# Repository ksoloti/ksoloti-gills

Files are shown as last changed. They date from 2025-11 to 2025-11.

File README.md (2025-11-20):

# ksoloti-gills
# CAD project and Gerbers for Ksoloti Gills v0.6

# Kicad 9.0!

## This is just the Gills unit (and CV expander) and will not work without a Ksoloti Core plugged in.

# Gills PCB
`Gerbers`, `BOM` and `CPL` files for the PCB are in the subfolder [/jlcpcb/production_files](https://github.com/ksoloti/ksoloti-gills/tree/main/jlcpcb/production_files)

Schematics are [here](https://github.com/ksoloti/ksoloti-gills/blob/main/ksoloti-gills_v06.pdf)

Human-readable BOM with notes and links is [here](https://github.com/ksoloti/ksoloti-gills/blob/main/ksoloti-gills_v06_bom.xlsx)

Screenshot from 2025-11-19 20-59-49

Screenshot from 2025-11-19 20-59-14

Screenshot from 2025-11-19 20-59-08

# Gills Enclosure Panels

`Gerbers` for the enclosure panels are in the subfolder [/ksoloti-gills_panel/jlcpcb/production_files](https://github.com/ksoloti/ksoloti-gills/tree/main/ksoloti-gills_panel/jlcpcb/production_files)
Although the Kicad project includes all panels, there is one gerber zip per panel: top, bottom, left, right, front, rear. If you have made edits and want to update the Gerbers, you will need to create separate Gerbers by pasting each relevant single panel in a temporary PCBNew window and `File->Plot...` it from there. Or so.
Note that there are two `ksoloti-gills-panel-top-*.zip`, one for black color, one for white. The silkscreens differ.

Screenshot from 2025-11-20 00-12-38

# Gills CV Expander PCB
`Gerbers`, `BOM` and `CPL` files for the CV Expander PCB are in the subfolder [/ksoloti-gills-cv-expander/jlcpcb/production_files](https://github.com/ksoloti/ksoloti-gills/tree/main/jlcpcb/production_files)

CV Expander Schematics are [here](https://github.com/ksoloti/ksoloti-gills/blob/main/ksoloti-gills-cv-expander/ksoloti-gills-cv-expander_v03.pdf)

BOM parts required for CV Expander are included in the main BOM (xlsx) above.

Screenshot from 2025-11-20 00-50-47

Screenshot from 2025-11-20 00-50-07

Screenshot from 2025-11-20 00-50-03

## About Licensing and Sharing 

This hardware design is shared under the "Creative Commons Attribution 4.0 International Public License" (CC BY 4.0).
This means you can use this design for almost anything, including commercial projects. You are totally free to reproduce, share, and modify it.

Because this is a physical hardware project, we ask for two small favours to keep the attribution clear:
- Keep the attribution text "CC BY 4.0 Ksoloti" on the silkscreen layer.
- If you make any significant edits and share your modified version, please note what modifications you've made. Do add something like "edit by <yourname>" if you like!

The full, official legal text is available in the `LICENSE` file in this repository. Happy hacking!

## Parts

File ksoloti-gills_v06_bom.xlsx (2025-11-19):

Source: | ksoloti_gills_v06
Date: | 14 Nov 2025 15:10:09 CST
Ref | Qnty | Value | Cmp name | Footprint | Description | Example
C53 | 1 | 1000uF – 2200uF, 10V+ | C_Polarized_Small | Capacitor_THT:CP_Radial_D10.0mm_P5.00mm | Polarized capacitor, small symbol
ENC1 | 1 | STEC11 | RotaryEncoder_Switch_GND | Library:ALPS_STEC11 | Rotary encoder, dual channel, incremental quadrate outputs, with switch, 20mm shaft | (T18 shaft:) https://www.amazon.com/Taiss-Detents-Points-Encoder-Diameter/dp/B07F24TRYG (D-shaft:) https://www.mouser.com/ProductDetail/Alps-Alpine/EC11E1534408?qs=PoKhxlfUXjJk5yy1jIb28A%3D%3D
H1, H3 | 2 | Conn_02x12_Female | Conn_02x12_Female | Library:PinSocket_2x12_P2.54mm_Vertical_smcrt_sqr | Generic connector, double row, 02x12, script generated (kicad-library-utils/schlib/autogen/connector/)
H2 | 2 | Conn_02x02_Female | Conn_02x02_Female | Library:PinSocket_2x02_P2.54mm_Vertical_smcrt_sqr | Generic connector, double row, 02x02, script generated (kicad-library-utils/schlib/autogen/connector/)
J1 | 1 | 9-20VDC | Barrel_Jack_Switch | Library:dc_socket_2.1mm_5.5mm | DC Barrel Jack with an internal switch | https://www.mouser.com/ProductDetail/Gravitech/CON-SOCJ-2155?qs=fkzBJ5HM%252BdCcpvFQyQZHtA%3D%3D
J3, J4, J5, J6, J7 | 5 | IN_L, IN_R, OUT_L, OUT_R, HP_OUT | AudioJack3_Switch | Library:Jack_6.35mm_Neutrik_NRJ6HF_Horizontal_no_screwhole | Audio Jack, 3 Poles (Stereo / TRS), Switched Poles (Normalling) | https://www.mouser.com/ProductDetail/Neutrik/NRJ6HF-1?qs=lytv%2F56AjyI%252Bc%252Bp%2FfWZpBw%3D%3D
J3n, J4n, J5n, J6n | 4 | JUST_NUTS | AudioJack3_Switch_nut | Library:Jack_6.35mm_Neutrik_NRJ6HF_Horizontal_no_screwhole_nut | Plastic nut for Audio Jack, 3 Poles (Stereo / TRS), Switched Poles (Normalling) | https://www.mouser.com/ProductDetail/Neutrik/NRJ-NUT-B?qs=S12Y1JoqO2A%2FB2tjq8cO2w%3D%3D
J8, J9 | 3 | EXP_IO1, EXP_IO2, GATE_OUT | AudioJack4 | Library:PJ-320A_THT | Audio Jack, 4 Poles (TRRS) | https://42keebs.eu/shop/parts/components/pj-320-trrs-socket/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 https://www.taydaelectronics.com/pj-320a-3-5-mm-audio-socket-through-hole-pcb-silver-plated.html
J10, J11 | 2 | MIDI_OUT, MIDI_IO | DIN-5_180degree | Library:MIDI_DIN-5_DS-5-01c | 5-pin DIN connector (5-pin DIN-5 stereo) | https://www.mouser.com/ProductDetail/Kycon/KCDX-5S-N?qs=uMQTibCNu0QKDGeRAj6hLg%3D%3D
J12 | 1 | LINE_IN_OUT | Conn_01x06_Female | Connector_PinSocket_2.54mm:PinSocket_1x06_P2.54mm_Vertical | Generic connector, single row, 01x06, script generated (kicad-library-utils/schlib/autogen/connector/)
J13 | 1 | HP_OUT | Conn_01x03_Female | Connector_PinSocket_2.54mm:PinSocket_1x03_P2.54mm_Vertical | Generic connector, single row, 01x03, script generated (kicad-library-utils/schlib/autogen/connector/)
LED1 | 1 | GREEN | LED | Library:LED_D3.0mm_marked | Light emitting diode | https://www.mouser.com/ProductDetail/Kingbright/WP710A10SGD?qs=jBF9H7RTBaS5vBvRdVQZww%3D%3D
LED2 | 1 | RED | LED | Library:LED_D3.0mm_marked | Light emitting diode | https://www.mouser.com/ProductDetail/Kingbright/WP710A10ID?qs=wRBQ8ZgBZ98VyHeNIlWGkQ%3D%3D
LED3, LED4 | 2 | LED_Dual_AKA | LED_Dual_AKA | Library:LED_D3.0mm-3_marked | Dual LED, common cathode on pin 2 | https://www.mouser.com/ProductDetail/Kingbright/WP115VEGW?qs=58z0TXQGVSQe%2FVnyoskf7A%3D%3D
LED standoffs | 4 | LED standoffs | LED standoffs | - | Standoffs for 3mm LED, plastic, 4mm height. 2 pcs for 2-pin LED, 2 pcs for 3-pin LED.
OLED1 | 1 | 128x64_OLED | display_i2c_oled | Library:128x64OLED_1_3in, SH1106, white | 1.3inch OLED, 4-pin header, I2c, SH1106, white, pinout GND-VCC-SCL-SDA. Exact dimensions are a bit tricky to get as there are various manufacturers. The one used in Gills is by Shenzhen Enrich Electronics, model ENH-OB0130011A
RV1, RV2, RV3, RV4, RV5, RV6, RV7, RV8, RV9, RV10 | 10 | B10k | R_POT_GND | Library:ALPS_POT_VERTICAL_PS | Potentiometer
RV11, RV12 | 2 | 2*B100k | R_POT_Dual_Separate_GND | Library:ALPS_POT_VERTICAL_PS_DUAL | Dual potentiometer, separate units
SW1, SW2, SW3, SW4 | 4 | TL1105 | TL1105 | Library:TL1105T | Double Pole Single Throw (DPST) Switch Momentary tact switch, 6*6mm. With 6.5mm diameter circular cap. | (standard click:) https://www.mouser.com/ProductDetail/CUI-Devices/TS02-66-120-BK-160-LCR-D?qs=A6eO%252BMLsxmT55wwvoE7v5Q%3D%3D (very light click:) https://www.mouser.com/ProductDetail/CUI-Devices/TS02-66-120-BK-100-LCR-D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
H1, H2, H3 (Core) | 3 | Conn_02x12_Male | Conn_02x12_Male | Library:PinHeader_2x12_P2.54mm_Vertical_smcrt_sqr | Generic connector, double row, 02x12, script generated (kicad-library-utils/schlib/autogen/connector/)
J1 (Core) | 1 | Conn_01x06_Male | Conn_01x06_Male | Library:PinHeader_1x06_P2.54mm_Vertical_smcrt_sqr | Generic connector, single row, 01x06, script generated (kicad-library-utils/schlib/autogen/connector/)
J2 (Core) | 1 | Conn_01x03_Male | Conn_01x03_Male | Library:PinHeader_1x03_P2.54mm_Vertical_smcrt_sqr | Generic connector, single row, 01x03, script generated (kicad-library-utils/schlib/autogen/connector/)
PDM mic header (Core) | 1 | Conn_01x02_Male | Conn_01x02_Male | Library:PinHeader_1x02_P2.54mm_Vertical_smcrt_sqr | Optional. Connects the digital Mic clock and data lines to the Core.
J1 (CV Expander) | 1 | Conn_02x03_Male | Conn_02x03_Male | Library:PinHeader_2x03_P2.54mm_Vertical_smcrt_sqr | Generic connector, double row, 02x03, script generated (kicad-library-utils/schlib/autogen/connector/)
TR1, TR2, TR3, TR4 (CV Expander) | 4 | 50k | Trimmer Bourns 3266P | Potentiometer_THT:Potentiometer_Bourns_3266P_Horizontal | Trimmer Potentiometer, Bourns 3266P Horizontal, 50k | https://www.digikey.tw/en/products/detail/bourns-inc/3266P-1-503/3722092
HEAT1 | 1 | Isolation tape, or Heatshrink, 3-4mm diameter, ca. 3cm length (optional) |  |  | Optional. For shielding LED1 and LED2 against light bleed from each other.
J14 (HP_POT) | 1 | 2*B1k to 2*B5k | R_POT_Dual_Separate_GND | Library:ALPS_POT_VERTICAL_PS_DUAL_HORIZONTAL | Optional headphone control. Involves drilling a hole. B1k recommended but can be as low as 500R or as high as 5k, with varying response. See “Optional Headphone Volume Control” here: ksoloti.github.io/6-1-gills_build_guide.html | Example (the right value may not be in stock!): smallbear-electronics.mybigcommerce.com/dual-gang-9mm-pc-mount/
U1 | 1 | M24512 | EEPROM | Package_SO:SOIC-8_3.9x4.9mm_P1.27mm | Optional 512kbit (64kByte) I2C EEPROM. STMicroelectronics M24512-RMN6 or M24512-WMN6 recommended. | https://www.mouser.tw/ProductDetail/STMicroelectronics/M24512-RMN6TP?qs=Mr75jesUWTdqo%252BCvXQQhAg%3D%3D https://www.mouser.tw/ProductDetail/STMicroelectronics/M24512-WMN6TP?qs=Djavi1aLnwqcyh9vtkZgnQ%3D%3D
Core PCB | 1 | Core PCB | Core PCB |  | Core PCB, 59mm * 89mm
Gills PCB | 1 | Gills PCB | Gills PCB |  | Gills PCB, 150mm * 92mm
Gills CV Expander PCB | 1 | Gills CV Expander PCB | Gills CV Expander PCB |  | Gills CV Expander PCB, 74mm * 70.5mm
Gills Enclosure | 1 | Gills Enclosure | Gills Enclosure |  | Gills enclosure consisting of 6 PCB panels: top, bottom, left, right, front, rear.
Hardware | 5 | M3 standoff, brass, male/female, 10mm | M3 standoff, brass, male/female, 10mm |  | Fix Gills enclosure top panel to Gills PCB
Hardware | 4 | M3 standoff, brass, female/female, 20mm | M3 standoff, brass, female/female, 20mm |  | Fix Gills enclosure bottom panel to Gills PCB
Hardware | 2 | M3 standoff, brass, male/female, 12mm | M3 standoff, brass, male/female, 12mm |  | Fix Ksoloti Core to Gills PCB
Hardware | 3 | M3 standoff, nylon, male/female, 6mm | M3 standoff, nylon, male/female, 6mm |  | Fix OLED display to Gills PCB
Hardware | 2 | M3 nut | M3 nut |  | Fix Ksoloti Core to Gills PCB
Hardware | 11 | M3 hex screw, black alloy, button head, 6mm | M3 hex screw, black alloy, button head, 6mm |  | 5 screws on top panel, 4 screws on bottom panel, 2 screws on OLED module
Hardware | 12 | Potentiometer nut, M6? M7? | Potentiometer nut, M6? M7? | Usually included with the pots | Encoder does not get one.

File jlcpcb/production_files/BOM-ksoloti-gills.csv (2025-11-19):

Comment | Designator | Footprint | LCSC | Quantity
100 ohm @ 100 Mhz | FB6,FB7 | R_0805_2012Metric | C1015 | 2
100 ohm @ 100 Mhz | FB1,FB2,FB3,FB4,FB5 | R_1206_3216Metric | C98293 | 5
100n | C11,C12,C13,C16,C29,C30,C33,C35,C39,C7,C8,C9 | C_0603_1608Metric | C14663 | 12
10k | R13,R31,R39,R40,R41,R44,R45 | R_0603_1608Metric | C25804 | 7
10n | C34 | C_0603_1608Metric | C57112 | 1
10u_25V | C10,C41 | C_0603_1608Metric | C96446 | 2
15uh | L1 | L_7.3x6.7_H3.5 | C2847544 | 1
1N4148WS | D4 | D_SOD-323 | C2128 | 1
1N5819WS | D5,D6,D7,D8 | D_SOD-323 | C191023 | 4
1k | R1,R12,R15,R16,R17,R19,R2,R3,R37,R4,R42,R43,R5,R6,R7,R8,R9 | R_0603_1608Metric | C21190 | 17
2.2u | C1,C2,C27,C28,C3,C31,C32,C4,C5,C6 | C_0603_1608Metric | C23630 | 10
2.7k | R35,R36 | R_0603_1608Metric | C13167 | 2
220 | R20,R21,R22,R23,R24,R33,R46,R48,R52,R53,R54,R55,R58,R59,R68 | R_0603_1608Metric | C22962 | 15
3V3 | D2 | D_MiniMELF | C7497475 | 1
3k | R49 | R_0603_1608Metric | C4211 | 1
47k | R25,R34,R47,R56,R57 | R_0603_1608Metric | C25819 | 5
47u | C36,C37,C38,C54 | C_1206_3216Metric | C96123 | 4
6N137 | U5 | SMDIP-8_W9.53mm | C110020 | 1
74LVC2G17 | U2,U9 | SOT-23-6 | C10429 | 2
M24512 | U1 | SOIC-8_3.9x4.9mm_P1.27mm | C79991 | 1
RGREEN | R10,R11,R18 | R_0805_2012Metric | C17630 | 3
RRED | R14,R32,R38 | R_0805_2012Metric | C17557 | 3
SS34 | D1,D3 | D_SMA | C8678 | 2
TPS5430DDA | U4 | TI_SO-PowerPAD-8_ThermalVias | C9864 | 1
MountingHole | MH7 | MountingHole_3.2mm_M3_Pad_Via_tight |  | 1
MountingHole | MH8 | MountingHole_3.2mm_M3_Pad_Via_tight |  | 1
MountingHole | MH5 | MountingHole_3.2mm_M3_Pad_Via_tight |  | 1
MountingHole | MH6 | MountingHole_3.2mm_M3_Pad_Via_tight |  | 1
B10k | RV1 | ALPS_POT_VERTICAL_PS |  | 1
LED_Dual_AKA | LED3 | LED_D3.0mm-3_marked |  | 1
B10k | RV4 | ALPS_POT_VERTICAL_PS |  | 1
LINE_IN_OUT | J12 | PinSocket_1x06_P2.54mm_Vertical |  | 1
LED_Dual_AKA | LED4 | LED_D3.0mm-3_marked |  | 1
B10k | RV2 | ALPS_POT_VERTICAL_PS |  | 1
2*B100k | RV11 | ALPS_POT_VERTICAL_PS_DUAL |  | 1
HP_POT | J14 | PinHeader_2x03_P2.54mm_Vertical |  | 1
TL1105 | SW1 | TL1105T |  | 1
TL1105 | SW4 | TL1105T |  | 1
TL1105 | SW2 | TL1105T |  | 1
B10k | RV3 | ALPS_POT_VERTICAL_PS |  | 1
MIDI_IO | J11 | MIDI_DIN-5_DS-5-01c |  | 1
B10k | RV10 | ALPS_POT_VERTICAL_PS |  | 1
B10k | RV9 | ALPS_POT_VERTICAL_PS |  | 1
B10k | RV6 | ALPS_POT_VERTICAL_PS |  | 1
MountingHole | MH4 | MountingHole_3.2mm_M3_Pad_Via_tight |  | 1
2*B100k | RV12 | ALPS_POT_VERTICAL_PS_DUAL |  | 1
RED | LED2 | LED_D3.0mm_marked |  | 1
STEC11 | ENC1 | ALPS_STEC12E08 |  | 1
B10k | RV7 | ALPS_POT_VERTICAL_PS |  | 1
TL1105 | SW3 | TL1105T |  | 1
B10k | RV5 | ALPS_POT_VERTICAL_PS |  | 1
MountingHole | MH1 | MountingHole_3.2mm_M3_Pad_Via_tight |  | 1
B10k | RV8 | ALPS_POT_VERTICAL_PS |  | 1
HP_OUT | J13 | PinSocket_1x03_P2.54mm_Vertical |  | 1
128x64_OLED | OLED1 | 128x64OLED_1_3in |  | 1
GREEN | LED1 | LED_D3.0mm_marked |  | 1
IN_L | J3 | Jack_6.35mm_Neutrik_NRJ6HF_Horizontal_no_screwhole |  | 1
Conn_01x01_Female | H2_P21 | PinSocket_1x01_P2.54mm_Vertical_smcrt_round |  | 1
Conn_01x01_Female | H1_P12 | PinSocket_1x01_P2.54mm_Vertical_smcrt_round |  | 1
Conn_01x01_Female | H3_P2 | PinSocket_1x01_P2.54mm_Vertical_smcrt_round |  | 1
Conn_01x01_Female | H1_P13 | PinSocket_1x01_P2.54mm_Vertical_smcrt_round |  | 1
Conn_01x01_Female | H3_P4 | PinSocket_1x01_P2.54mm_Vertical_smcrt_round |  | 1
Conn_01x01_Female | H1_P22 | PinSocket_1x01_P2.54mm_Vertical_smcrt_round |  | 1
Conn_01x01_Female | H3_P17 | PinSocket_1x01_P2.54mm_Vertical_smcrt_round |  | 1
Conn_01x01_Female | H3_P19 | PinSocket_1x01_P2.54mm_Vertical_smcrt_round |  | 1
HP_OUT | J7 | Jack_6.35mm_Neutrik_NRJ6HF_Horizontal_no_screwhole |  | 1
OUT_R | J6 | Jack_6.35mm_Neutrik_NRJ6HF_Horizontal_no_screwhole |  | 1
Conn_01x01_Female | H3_P22 | PinSocket_1x01_P2.54mm_Vertical_smcrt_round |  | 1
Conn_01x01_Female | H3_P15 | PinSocket_1x01_P2.54mm_Vertical_smcrt_round |  | 1
EXP_IO | J8 | PJ-320A_THT |  | 1
MIDI_OUT | J10 | MIDI_DIN-5_DS-5-01c |  | 1
Conn_01x01_Female | H3_P23 | PinSocket_1x01_P2.54mm_Vertical_smcrt_round |  | 1
Conn_01x01_Female | H3_P16 | PinSocket_1x01_P2.54mm_Vertical_smcrt_round |  | 1
Conn_01x01_Female | H1_P17 | PinSocket_1x01_P2.54mm_Vertical_smcrt_round |  | 1
Conn_01x01_Female | H3_P8 | PinSocket_1x01_P2.54mm_Vertical_smcrt_round |  | 1
Conn_01x01_Female | H3_P14 | PinSocket_1x01_P2.54mm_Vertical_smcrt_round |  | 1
Conn_01x01_Female | H1_P23 | PinSocket_1x01_P2.54mm_Vertical_smcrt_round |  | 1
Conn_01x01_Female | H2_P23 | PinSocket_1x01_P2.54mm_Vertical_smcrt_round |  | 1
Conn_01x01_Female | H3_P11 | PinSocket_1x01_P2.54mm_Vertical_smcrt_round |  | 1
Conn_01x01_Female | H2_P22 | PinSocket_1x01_P2.54mm_Vertical_smcrt_round |  | 1
Conn_01x01_Female | H1_P18 | PinSocket_1x01_P2.54mm_Vertical_smcrt_round |  | 1
Conn_01x01_Female | H3_P1 | PinSocket_1x01_P2.54mm_Vertical_smcrt_sqr |  | 1
Conn_01x01_Female | H3_P24 | PinSocket_1x01_P2.54mm_Vertical_smcrt_round |  | 1
Conn_01x01_Female | H1_P7 | PinSocket_1x01_P2.54mm_Vertical_smcrt_round |  | 1
Conn_01x01_Female | H3_P5 | PinSocket_1x01_P2.54mm_Vertical_smcrt_round |  | 1
Conn_01x01_Female | H3_P20 | PinSocket_1x01_P2.54mm_Vertical_smcrt_round |  | 1
Conn_01x01_Female | H3_P21 | PinSocket_1x01_P2.54mm_Vertical_smcrt_round |  | 1
OUT_L | J5 | Jack_6.35mm_Neutrik_NRJ6HF_Horizontal_no_screwhole |  | 1
Conn_01x01_Female | H1_P21 | PinSocket_1x01_P2.54mm_Vertical_smcrt_round |  | 1
9-20VDC | J1 | dc_socket |  | 1
Conn_01x01_Female | H1_P2 | PinSocket_1x01_P2.54mm_Vertical_smcrt_round |  | 1
Conn_01x01_Female | H1_P19 | PinSocket_1x01_P2.54mm_Vertical_smcrt_round |  | 1
Conn_01x01_Female | H1_P9 | PinSocket_1x01_P2.54mm_Vertical_smcrt_round |  | 1
Conn_01x01_Female | H1_P11 | PinSocket_1x01_P2.54mm_Vertical_smcrt_round |  | 1
Conn_01x01_Female | H3_P3 | PinSocket_1x01_P2.54mm_Vertical_smcrt_round |  | 1
Conn_01x01_Female | H1_P10 | PinSocket_1x01_P2.54mm_Vertical_smcrt_round |  | 1
PWR_SWITCH | J2 | PinHeader_1x02_P2.54mm_Vertical |  | 1
Conn_01x01_Female | H1_P3 | PinSocket_1x01_P2.54mm_Vertical_smcrt_round |  | 1
Conn_01x01_Female | H2_P24 | PinSocket_1x01_P2.54mm_Vertical_smcrt_round |  | 1
Conn_01x01_Female | H3_P10 | PinSocket_1x01_P2.54mm_Vertical_smcrt_round |  | 1
Conn_01x01_Female | H1_P8 | PinSocket_1x01_P2.54mm_Vertical_smcrt_round |  | 1
Conn_01x01_Female | H3_P18 | PinSocket_1x01_P2.54mm_Vertical_smcrt_round |  | 1
Conn_01x01_Female | H3_P7 | PinSocket_1x01_P2.54mm_Vertical_smcrt_round |  | 1
Conn_01x01_Female | H3_P12 | PinSocket_1x01_P2.54mm_Vertical_smcrt_round |  | 1
Conn_01x01_Female | H1_P15 | PinSocket_1x01_P2.54mm_Vertical_smcrt_round |  | 1
EXP_IO | J9 | PJ-320A_THT |  | 1
Conn_01x01_Female | H3_P9 | PinSocket_1x01_P2.54mm_Vertical_smcrt_round |  | 1
Conn_01x01_Female | H1_P6 | PinSocket_1x01_P2.54mm_Vertical_smcrt_round |  | 1
Conn_01x01_Female | H1_P20 | PinSocket_1x01_P2.54mm_Vertical_smcrt_round |  | 1
Conn_01x01_Female | H1_P4 | PinSocket_1x01_P2.54mm_Vertical_smcrt_round |  | 1
Conn_01x01_Female | H1_P24 | PinSocket_1x01_P2.54mm_Vertical_smcrt_round |  | 1
IN_R | J4 | Jack_6.35mm_Neutrik_NRJ6HF_Horizontal_no_screwhole |  | 1
Conn_01x01_Female | H3_P6 | PinSocket_1x01_P2.54mm_Vertical_smcrt_round |  | 1
Conn_01x01_Female | H3_P13 | PinSocket_1x01_P2.54mm_Vertical_smcrt_round |  | 1
Conn_01x01_Female | H1_P1 | PinSocket_1x01_P2.54mm_Vertical_smcrt_sqr |  | 1
Conn_01x01_Female | H1_P14 | PinSocket_1x01_P2.54mm_Vertical_smcrt_round |  | 1
Conn_01x01_Female | H1_P16 | PinSocket_1x01_P2.54mm_Vertical_smcrt_round |  | 1
Conn_01x01_Female | H1_P5 | PinSocket_1x01_P2.54mm_Vertical_smcrt_round |  | 1
LR_NORMAL | JP2 | SolderJumper-2_0603_Bridged_0_25mm |  | 1
EXPANSION | J16 | PinHeader_2x04_P2.54mm_Vertical |  | 1
MIDI1_CFG | J15 | PinHeader_2x03_P2.54mm_Vertical |  | 1
MIDI_OUT_GND | J18 | PinHeader_1x02_P2.54mm_Vertical |  | 1
2200u 10+V | C53 | CP_Radial_D10.0mm_P5.00mm |  | 1
OUTPUT_INSERT | J19 | PinHeader_1x05_P2.54mm_Vertical |  | 1
Adafruit_PDM_microphone_breakout | M1 | Adafruit PDM microphone breakout |  | 1
POWER_HEADER | J20 | PinHeader_1x03_P2.54mm_Vertical |  | 1
DMIC_CLK | H6_P2 | PinSocket_1x01_P2.54mm_Vertical_smcrt_round |  | 1
DMIC_DAT | H6_P1 | PinSocket_1x01_P2.54mm_Vertical_smcrt_round |  | 1
GATE_OUT | J17 | PJ-320A_THT |  | 1
Conn_01x01_Female | H2_P4 | PinSocket_1x01_P2.54mm_Vertical_smcrt_round |  | 1
Conn_01x01_Female | H2_P3 | PinSocket_1x01_P2.54mm_Vertical_smcrt_round |  | 1
Conn_01x01_Female | H2_P2 | PinSocket_1x01_P2.54mm_Vertical_smcrt_round |  | 1
Conn_01x01_Female | H2_P1 | PinSocket_1x01_P2.54mm_Vertical_smcrt_sqr |  | 1

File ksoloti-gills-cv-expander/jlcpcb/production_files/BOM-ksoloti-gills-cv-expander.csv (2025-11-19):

Comment | Designator | Footprint | LCSC | Quantity
100k | R7,R9 | R_0603_1608Metric | C25803 | 2
100n | C13,C14,C3,C4,C6,C7,C8 | C_0603_1608Metric | C14663 | 7
10k | R1,R4 | R_0603_1608Metric | C25804 | 2
10u | C2,C5 | C_0603_1608Metric | C96446 | 2
12k | R5 | R_0603_1608Metric | C22790 | 1
150k | R10,R8 | R_0603_1608Metric | C22807 | 2
1N5819 | D1,D2,D3 | D_SOD-323 | C191023 | 3
1k | R15,R16,R3,R6 | R_0603_1608Metric | C21190 | 4
2.2n | C17,C18 | C_0603_1608Metric | C1604 | 2
22u | C1,C10,C15,C16,C9 | C_0805_2012Metric | C45783 | 5
30k | R11,R12,R2 | R_0603_1608Metric | C22984 | 3
33uh | L1 | L_APV_ANR5020 | C842866 | 1
470n | C11,C12 | C_0603_1608Metric | C1623 | 2
50k | TR1,TR2,TR3,TR4 | Potentiometer_Bourns_3266P_Horizontal | C123432 | 4
68k | R13,R14 | R_0603_1608Metric | C23231 | 2
CJ431 | U4 | SOT-23W | C3113 | 1
L78L12_SOT89 | U2 | SOT-89-3_clearance | C915681 | 1
L79L12_SOT89 | U3 | SOT-89-3_clearance | C2847004 | 1
TL072 | U5 | SOIC-8_3.9x4.9mm_P1.27mm | C6961 | 1
XL6007 | U1 | SOIC-8-1EP_3.9x4.9mm_P1.27mm_EP2.41x3.81mm | C5240411 | 1
12V_PWR | J2 | PinHeader_1x03_P2.54mm_Vertical |  | 1
EXPANSION | J1 | PinHeader_2x03_P2.54mm_Vertical |  | 1

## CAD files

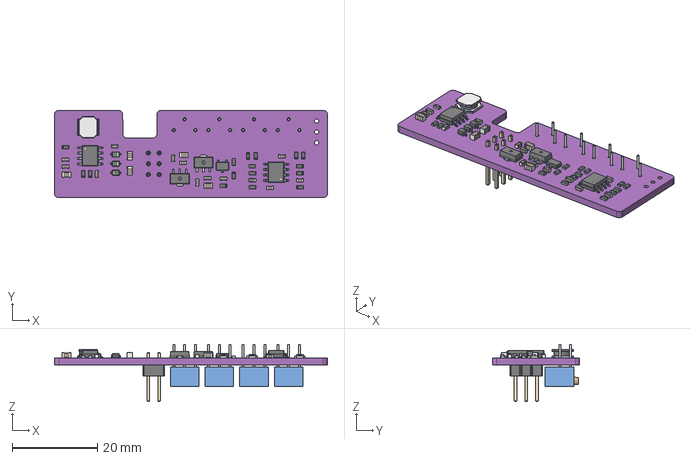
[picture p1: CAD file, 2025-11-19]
ksoloti-gills_cv_expander_rev3.step
64.0 x 20.5 x 13.4 mm
ksoloti_gill_stalks_cv_expander_rev3 PCB

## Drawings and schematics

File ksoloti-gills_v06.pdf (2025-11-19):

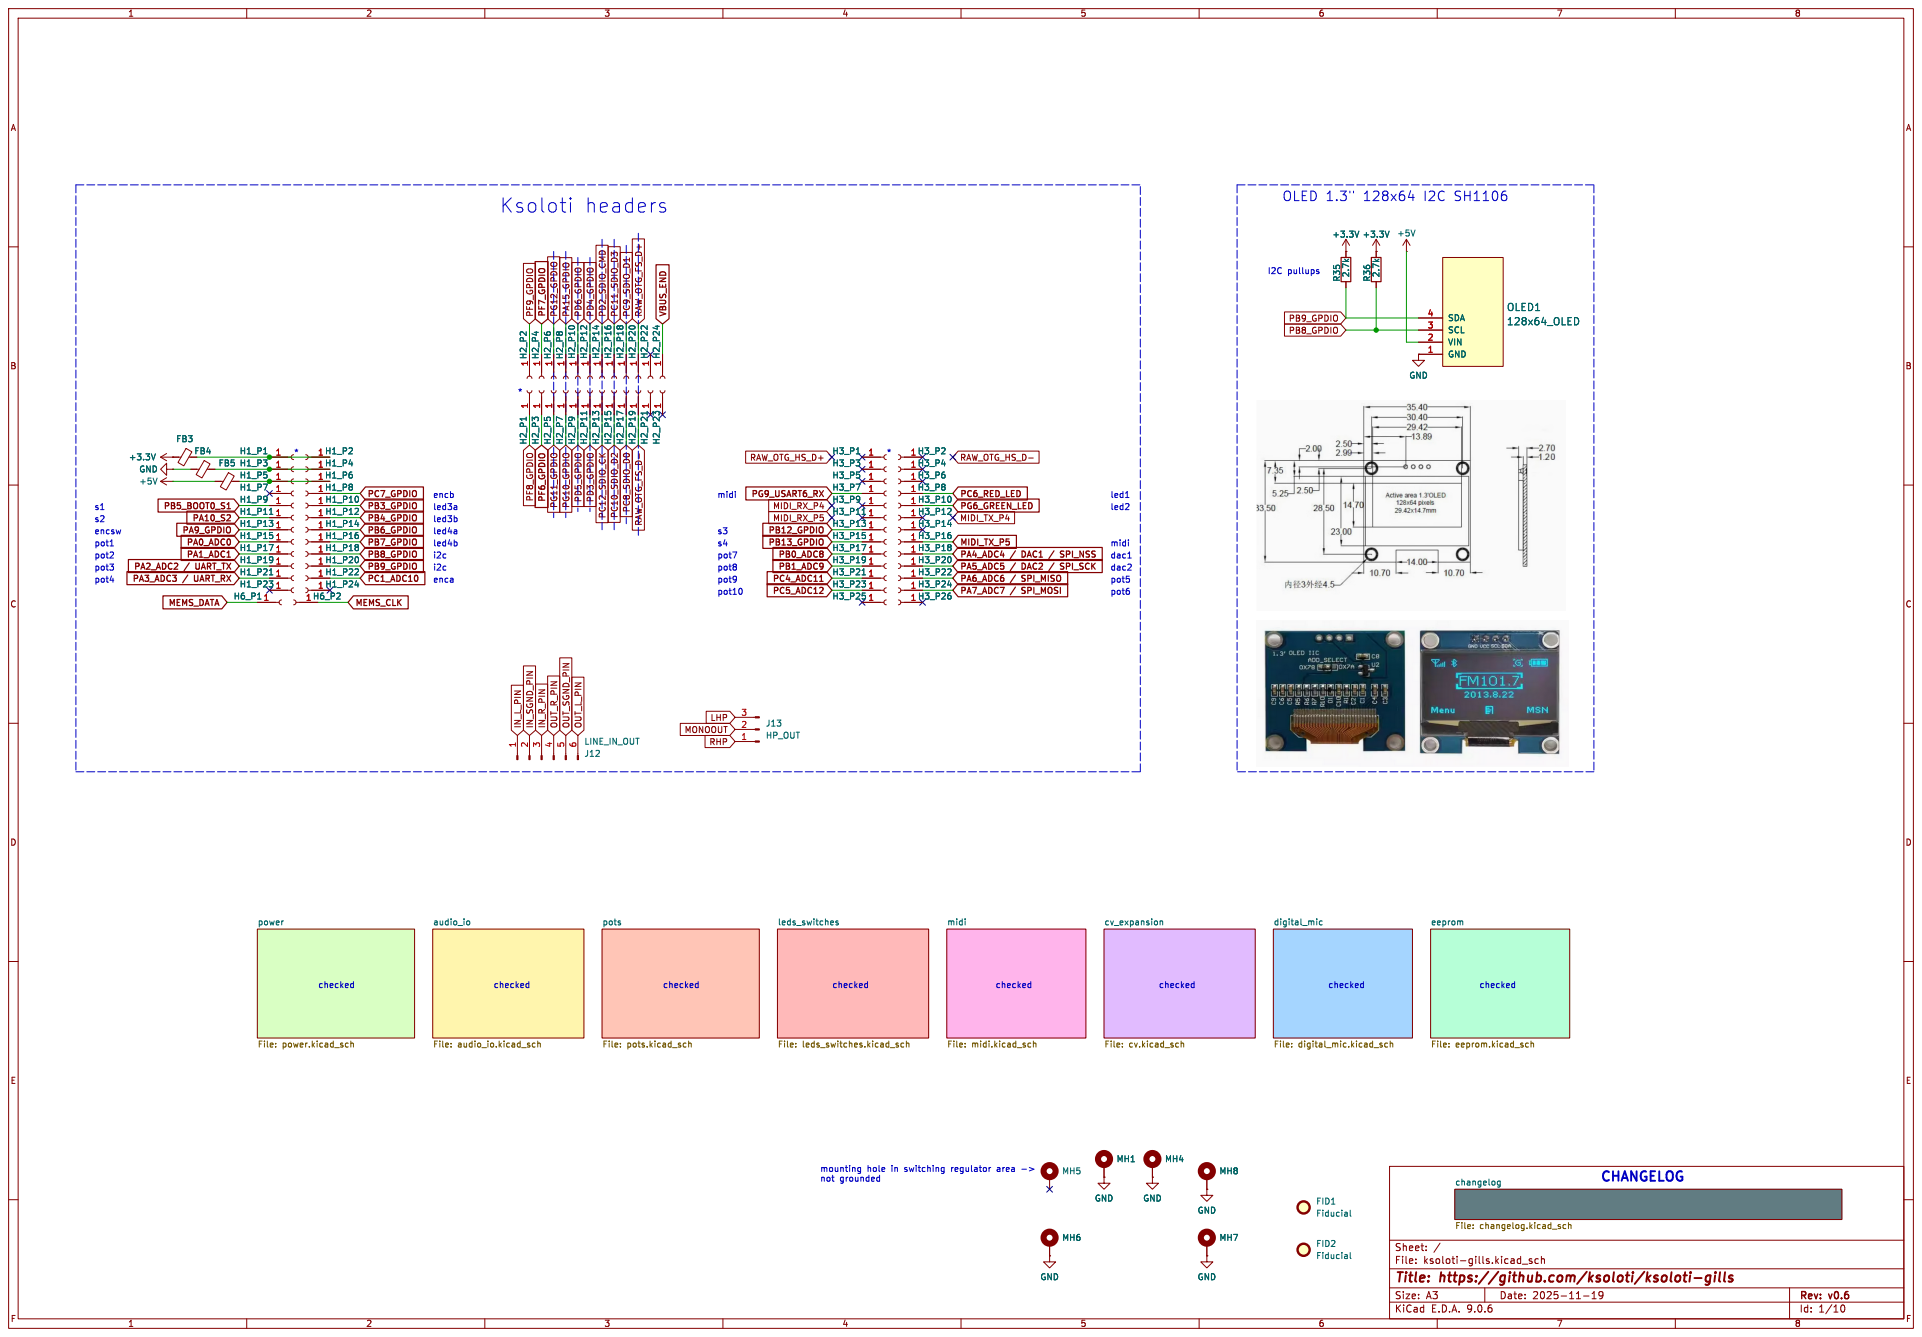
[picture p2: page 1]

Id: 1/10 Title: https://github.com/ksoloti/ksoloti-gills

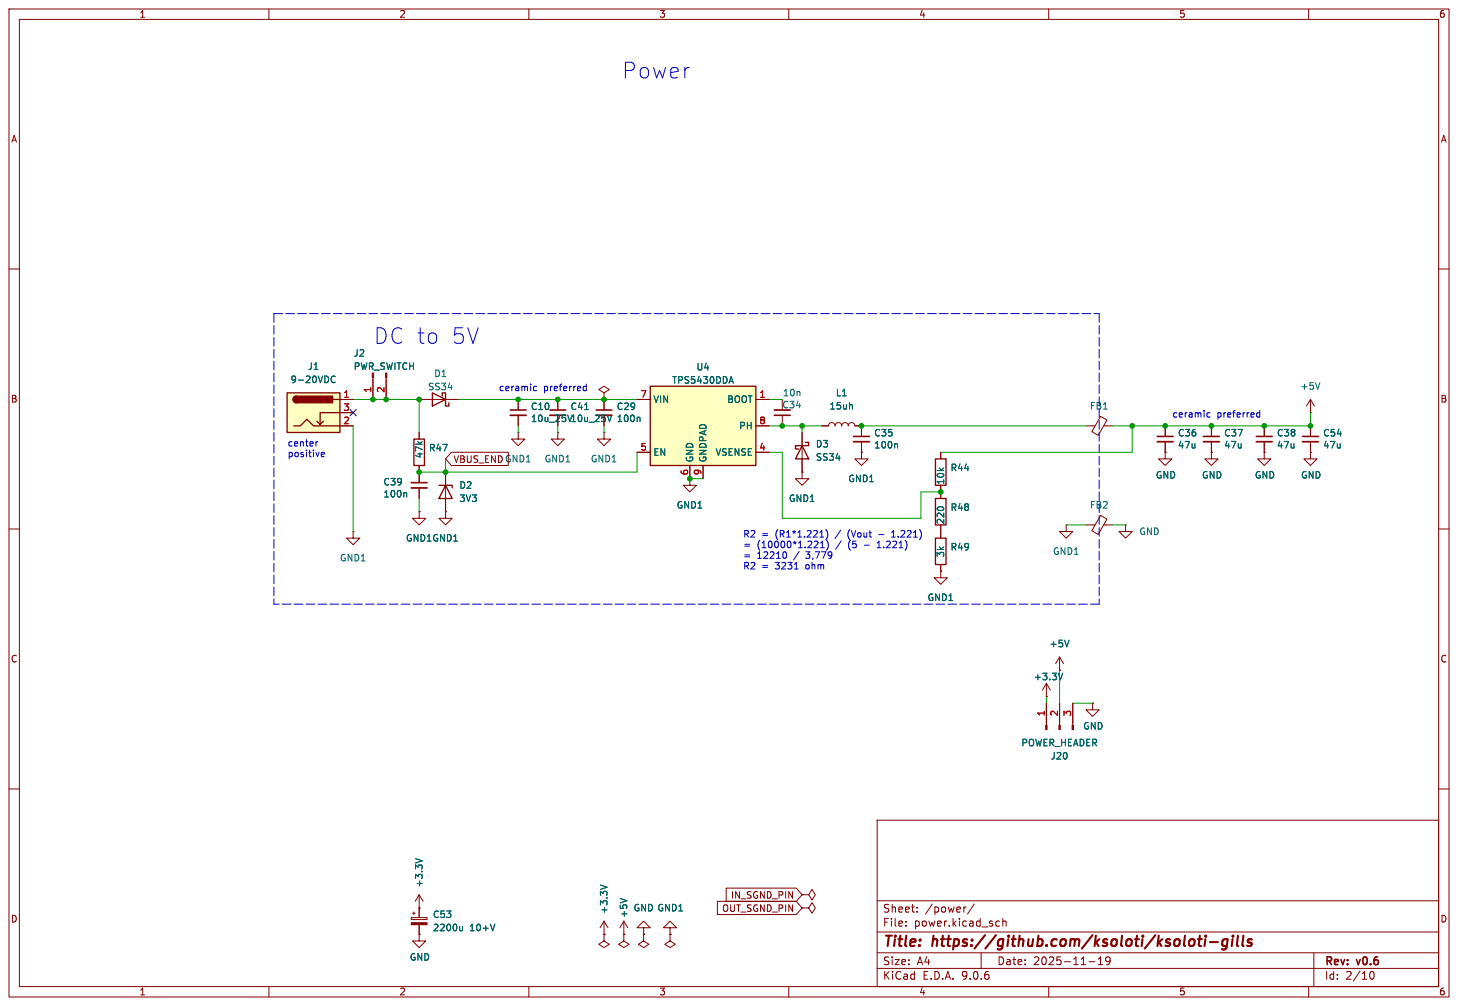
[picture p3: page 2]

File: power.kicad_sch Sheet: /power/
Id: 2/10 Title: https://github.com/ksoloti/ksoloti-gills

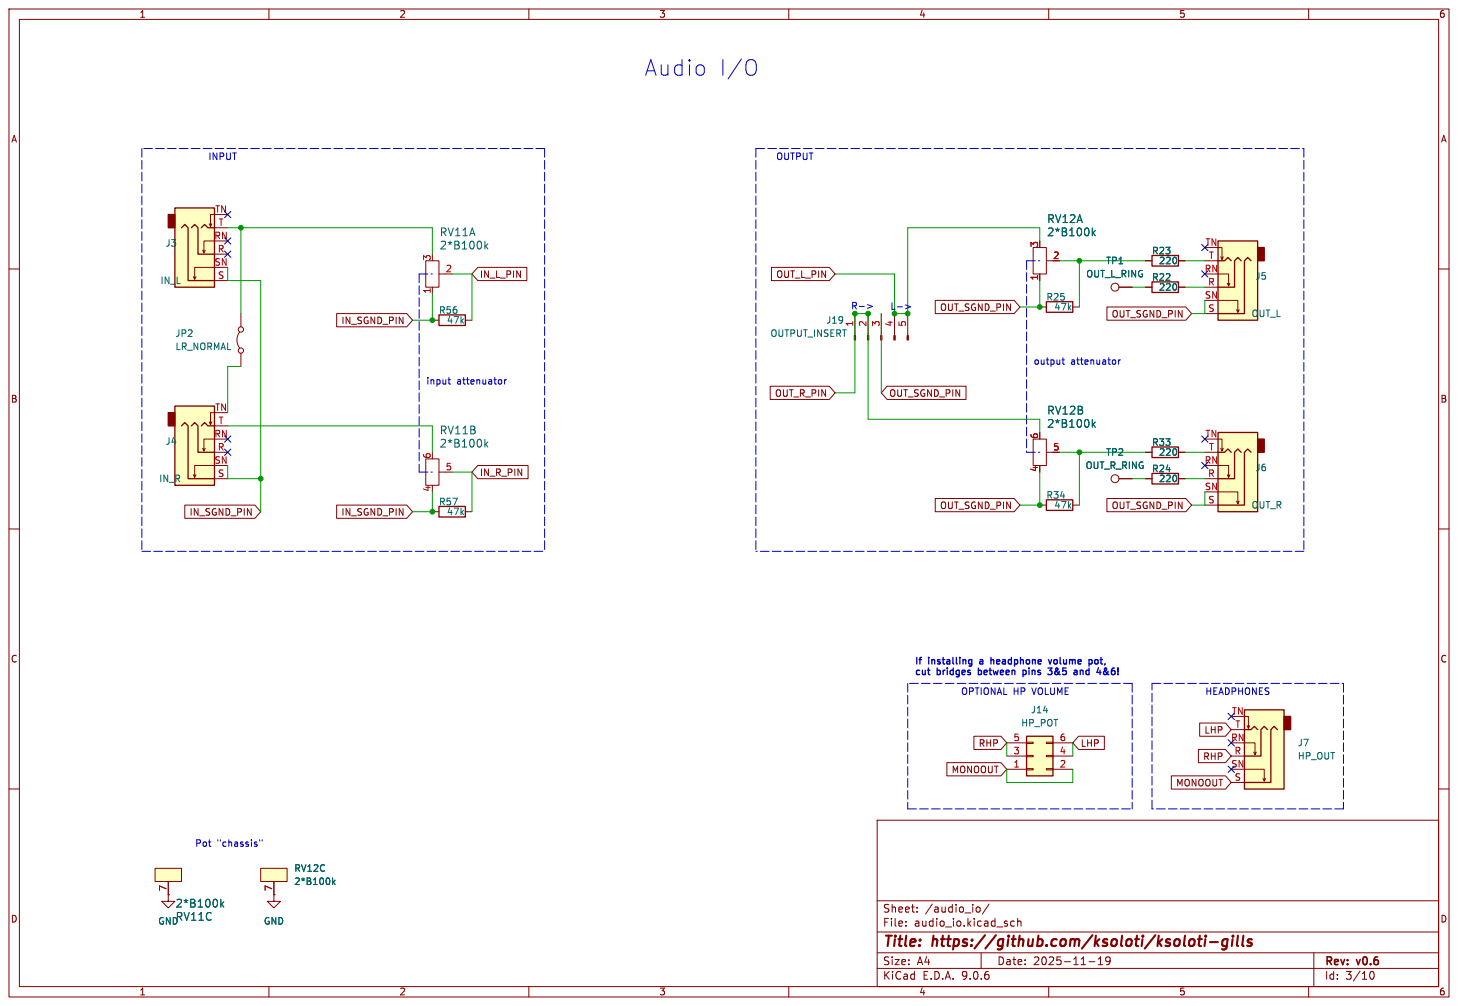
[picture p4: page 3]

output attenuator OPTIONAL HP VOLUME

File: audio_io.kicad_sch Sheet: /audio_io/
Id: 3/10 Title: https://github.com/ksoloti/ksoloti-gills

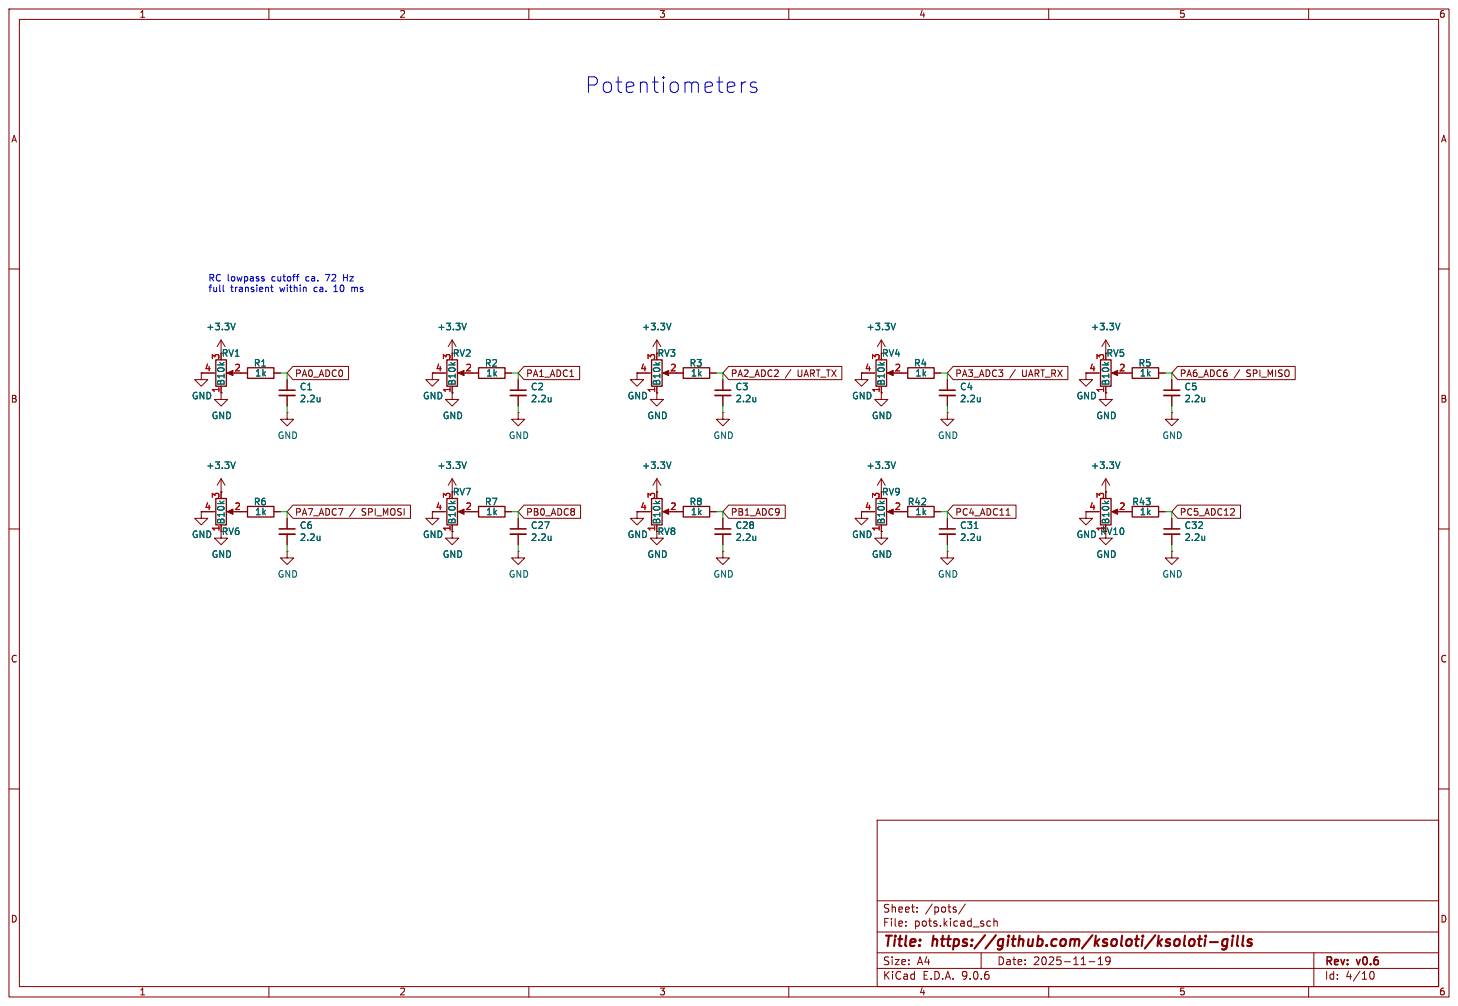
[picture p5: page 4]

RC lowpass cutoff ca. 72 Hz

File: pots.kicad_sch Sheet: /pots/
Id: 4/10 Title: https://github.com/ksoloti/ksoloti-gills

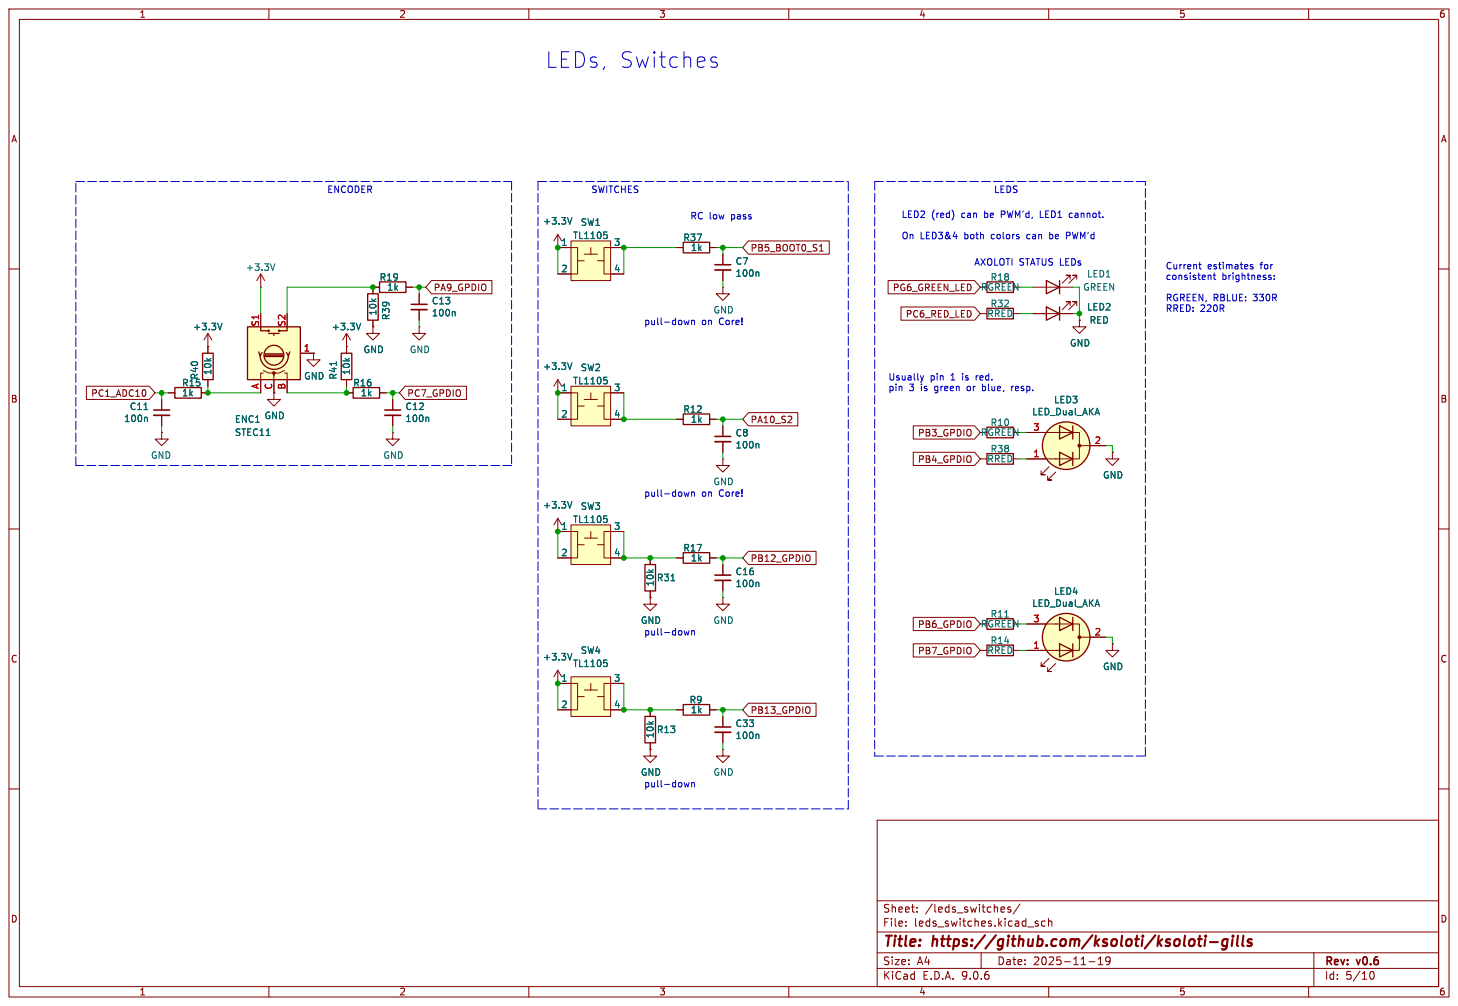
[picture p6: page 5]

Id: 5/10 Title: https://github.com/ksoloti/ksoloti-gills

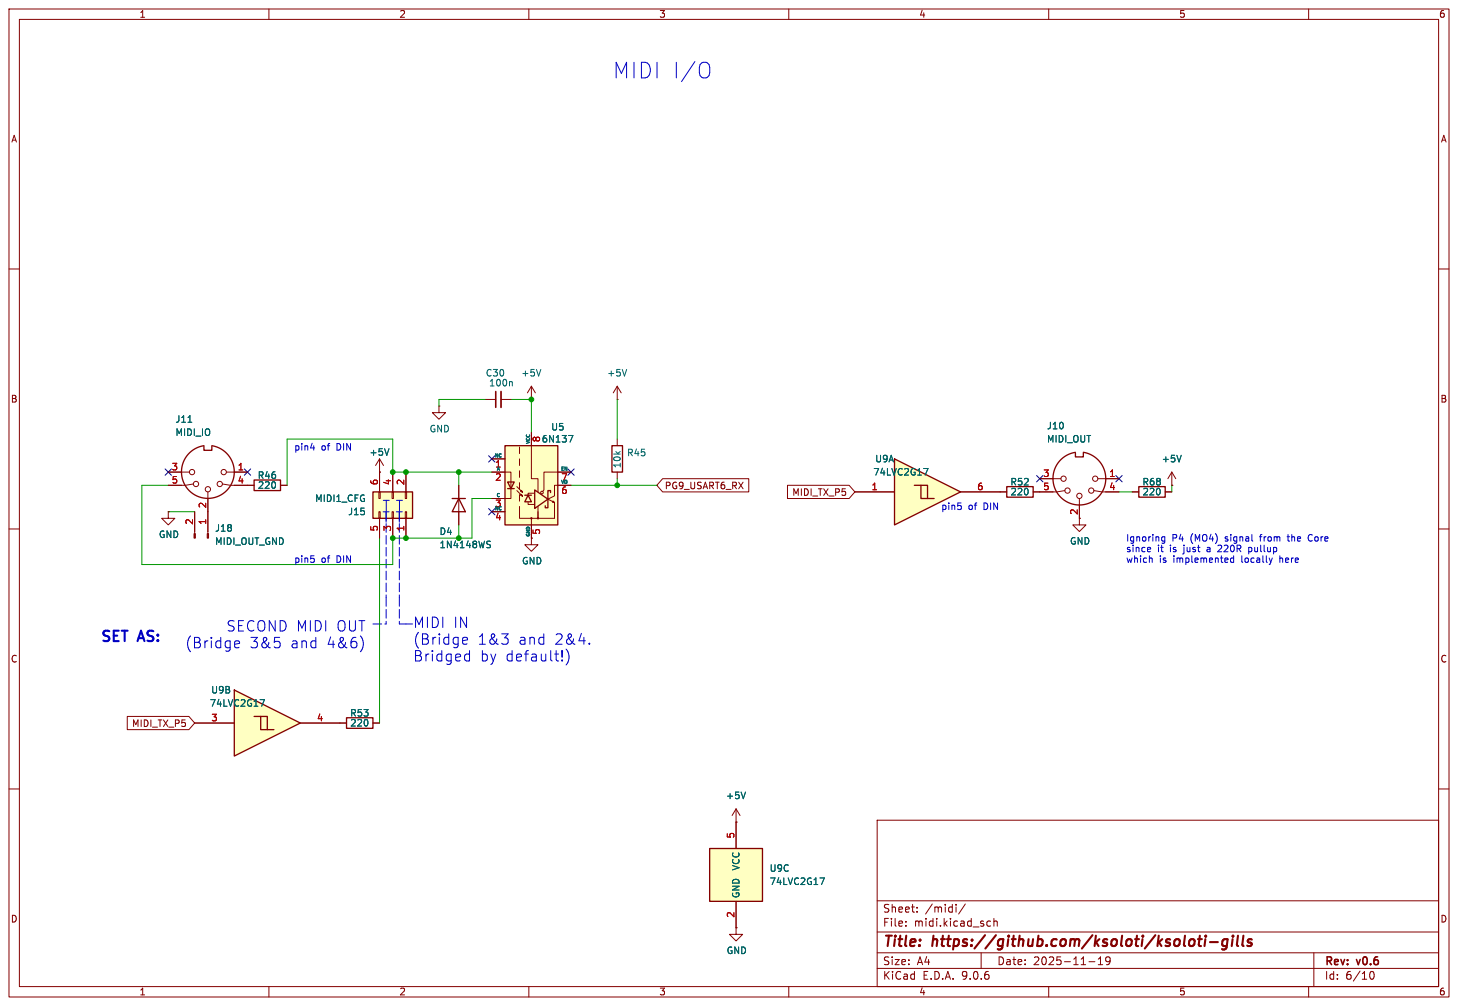
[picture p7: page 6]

File: midi.kicad_sch Sheet: /midi/
Id: 6/10 Title: https://github.com/ksoloti/ksoloti-gills

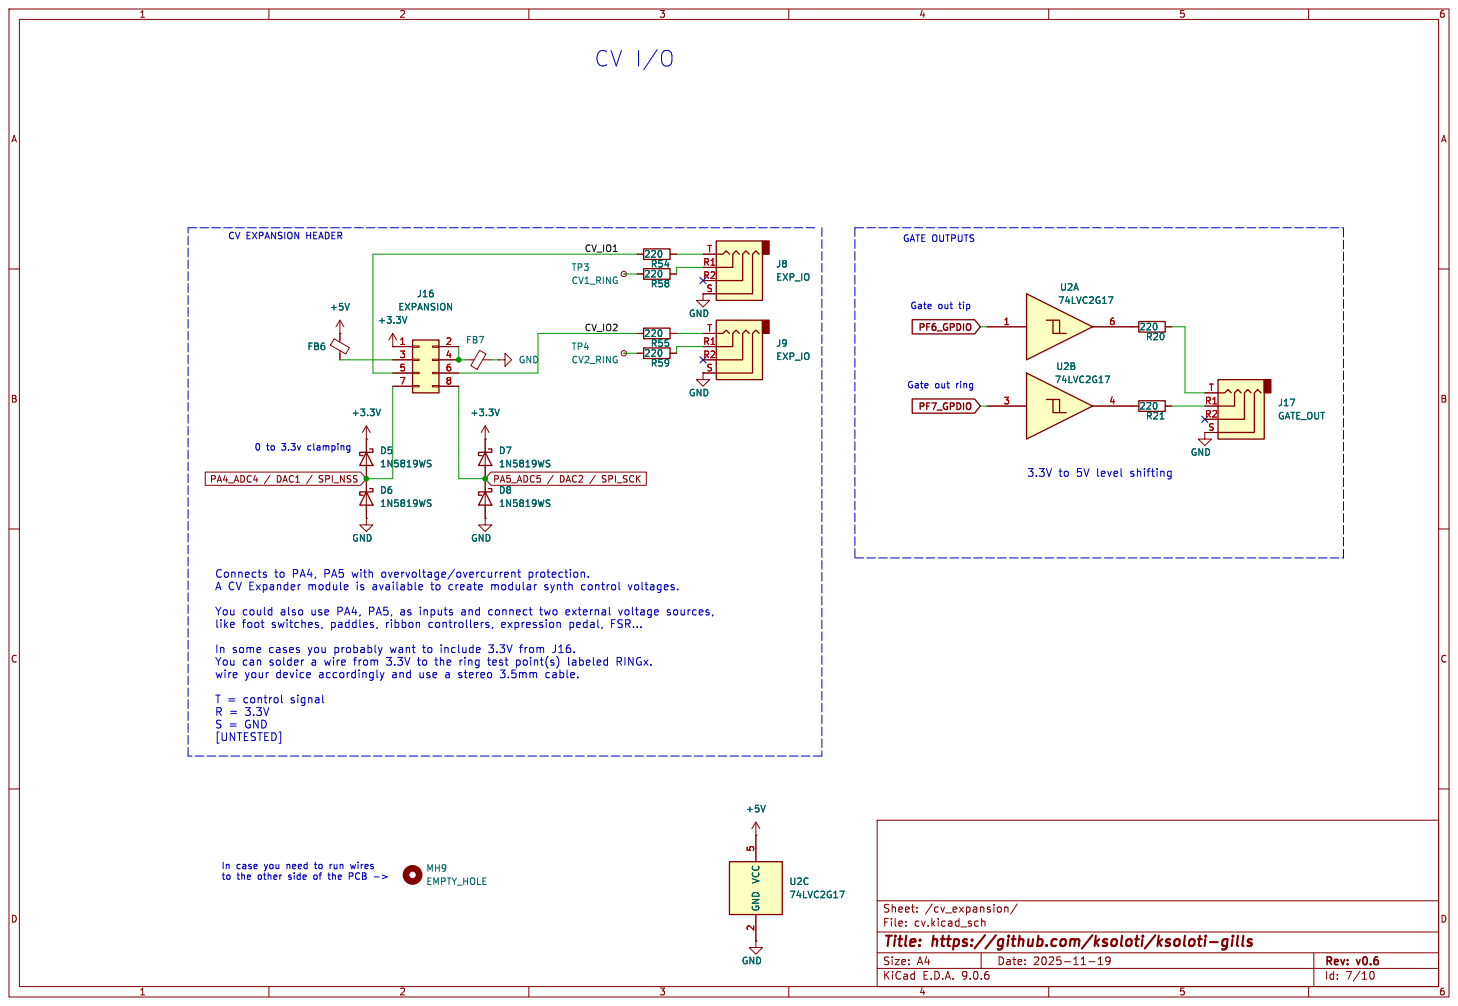
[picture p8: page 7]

0 to 3.3v clamping CV EXPANSION HEADER

In case you need to run wires

Id: 7/10 Title: https://github.com/ksoloti/ksoloti-gills

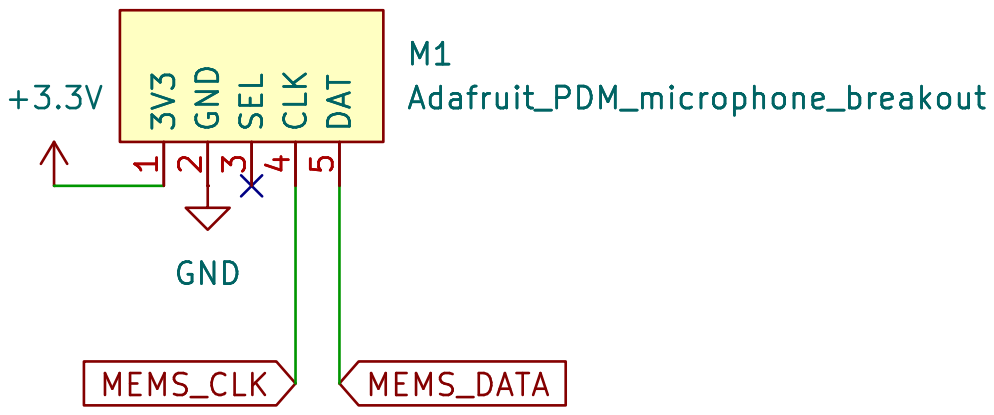
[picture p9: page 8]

File: digital_mic.kicad_sch Sheet: /digital_mic/
Id: 8/10 Title: https://github.com/ksoloti/ksoloti-gills

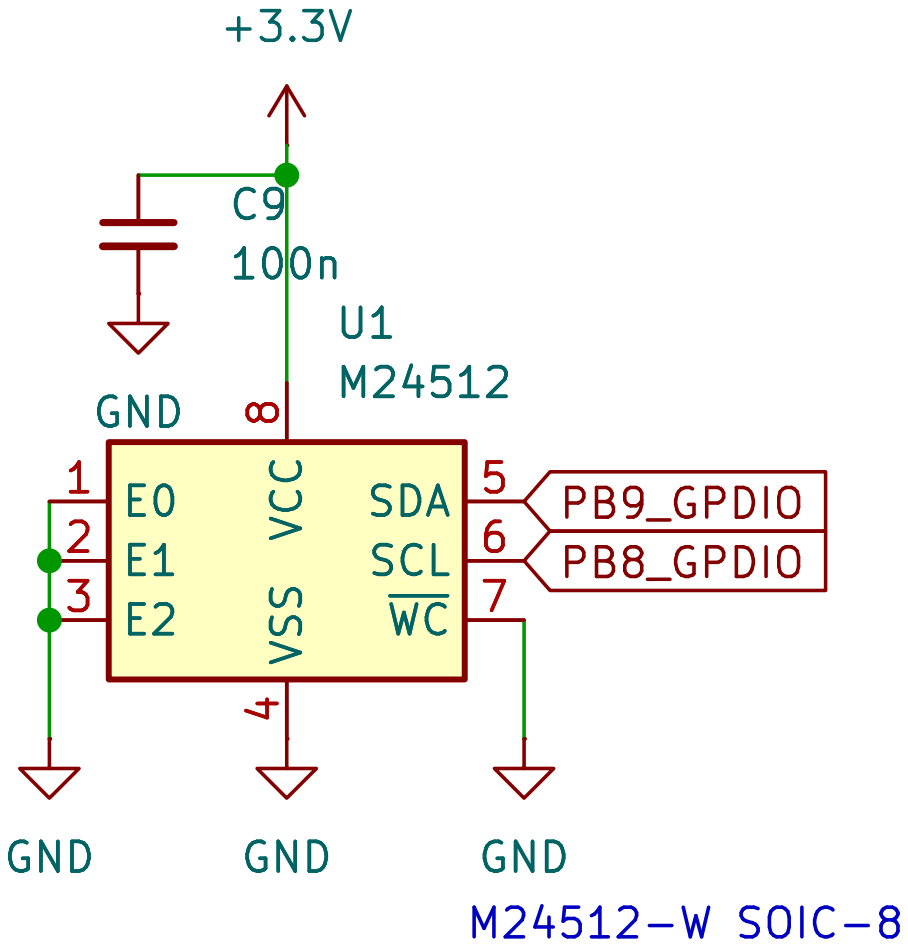
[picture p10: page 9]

4 SDA 5 SCL 6 ~{WC}7 U1 M24512 GND

4 SDA 5 SCL 6 ~{WC}7 GND GND

File: eeprom.kicad_sch Sheet: /eeprom/
Id: 9/10 Title: https://github.com/ksoloti/ksoloti-gills

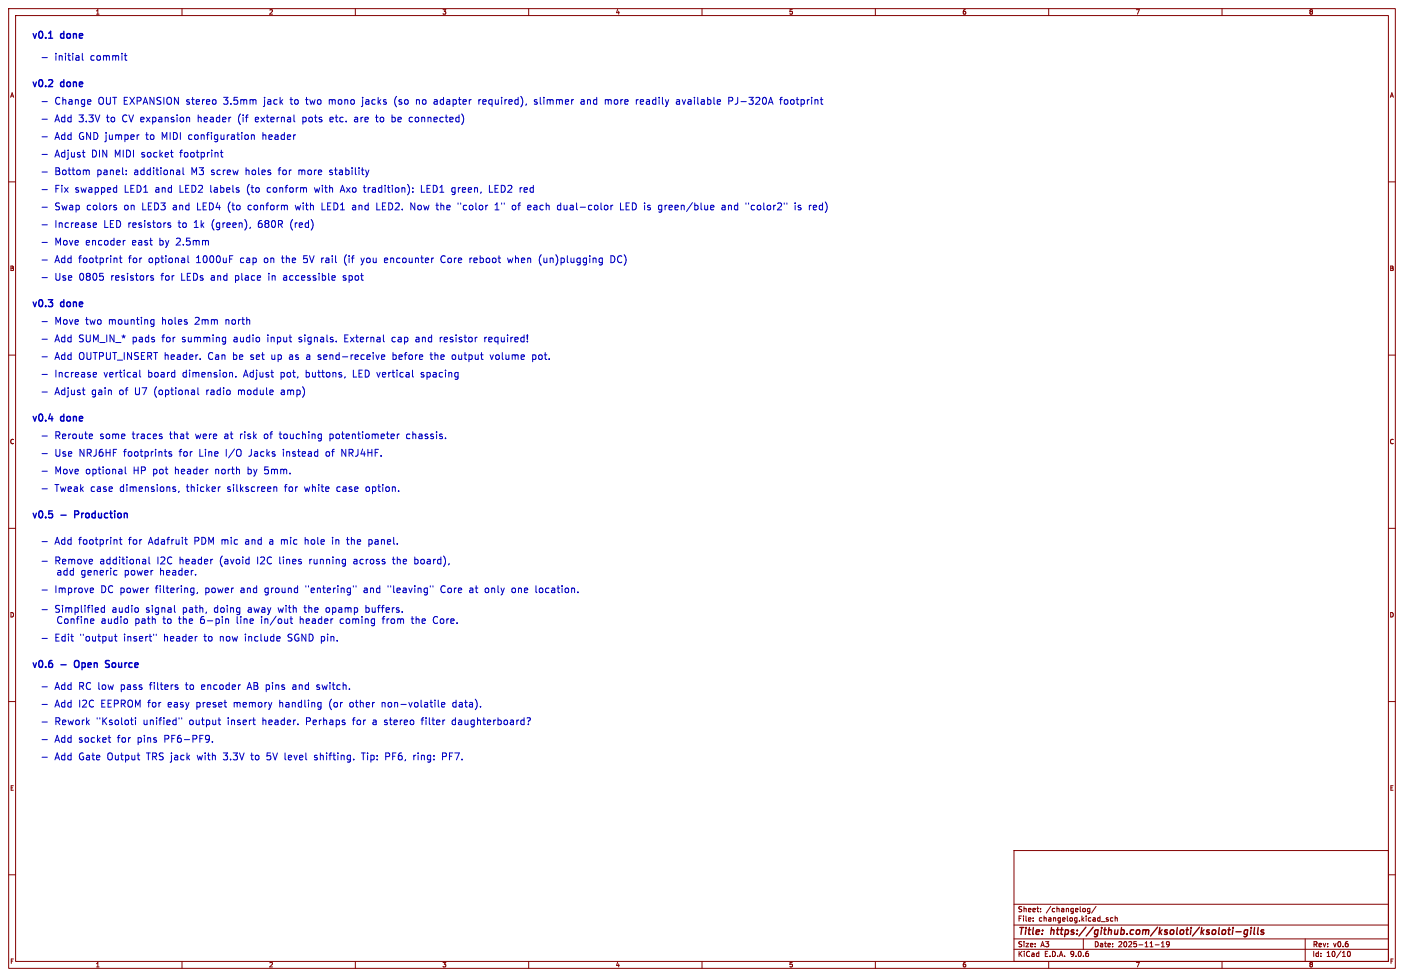
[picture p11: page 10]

- Move encoder east by 2.5mm

File: changelog.kicad_sch Sheet: /changelog/
Id: 10/10 Title: https://github.com/ksoloti/ksoloti-gills

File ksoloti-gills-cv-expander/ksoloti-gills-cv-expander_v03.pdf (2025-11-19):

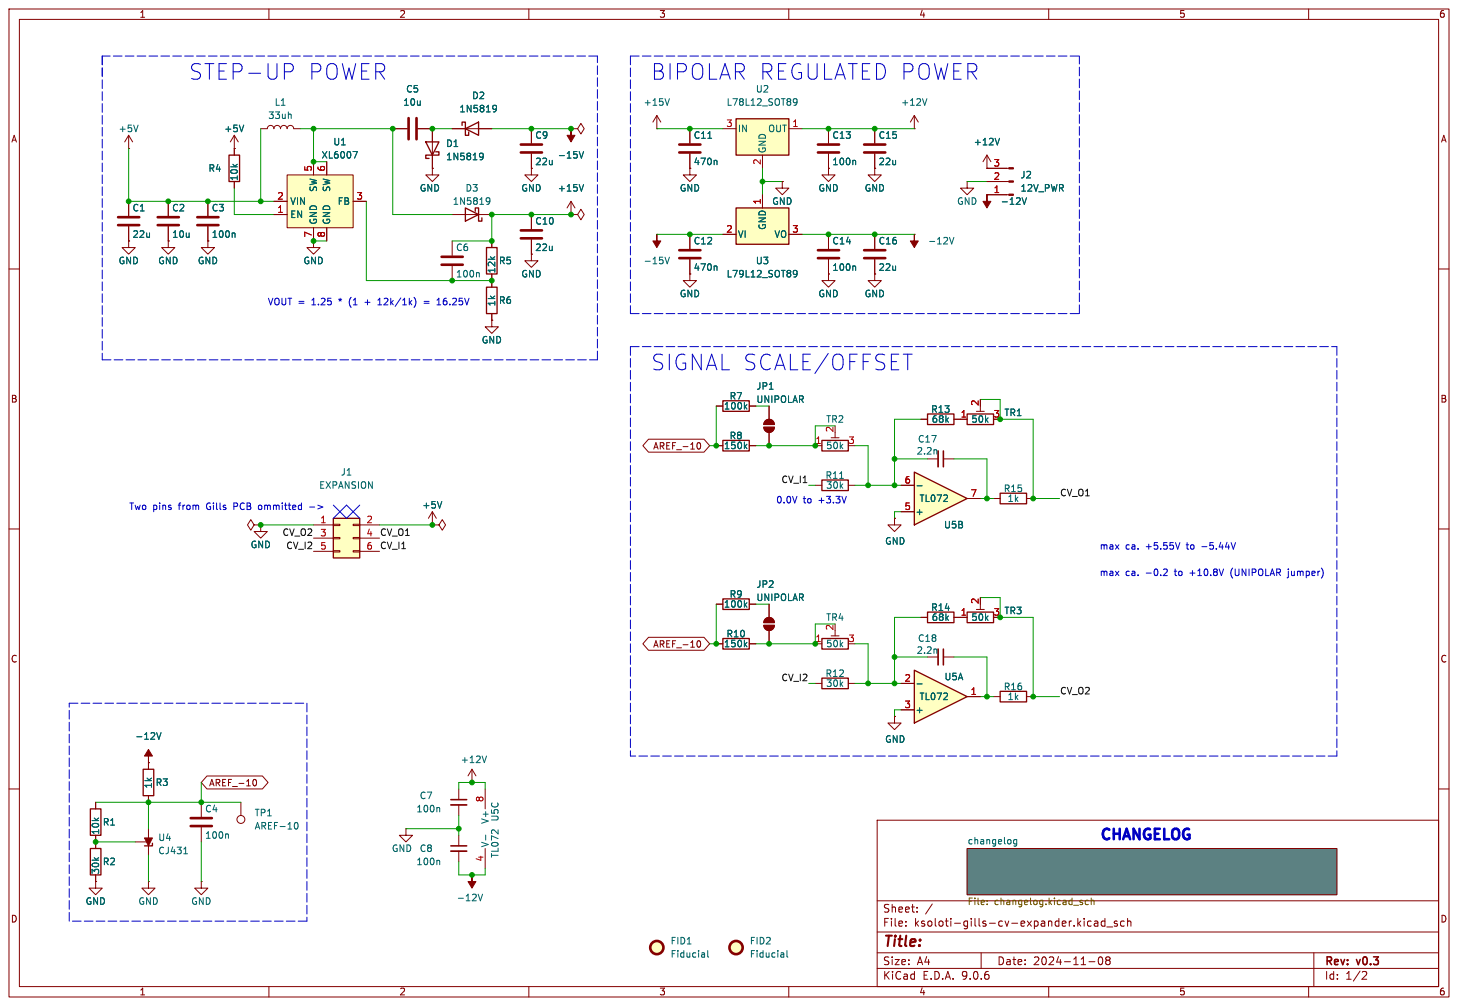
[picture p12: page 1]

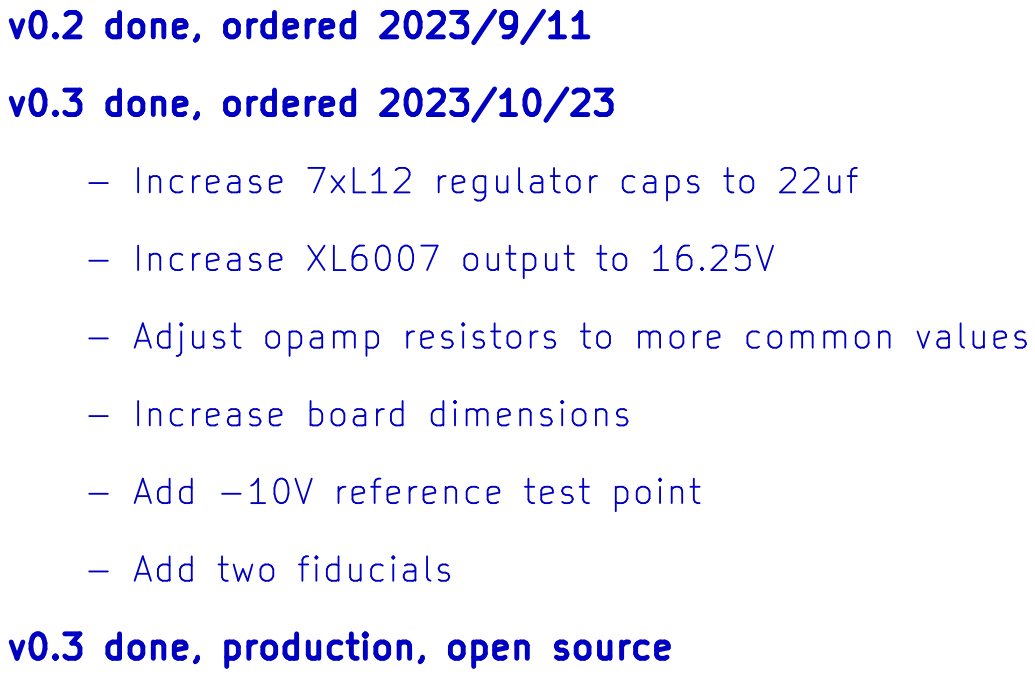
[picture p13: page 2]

Id: 2/2 Title: File: changelog.kicad_sch Sheet: /changelog/

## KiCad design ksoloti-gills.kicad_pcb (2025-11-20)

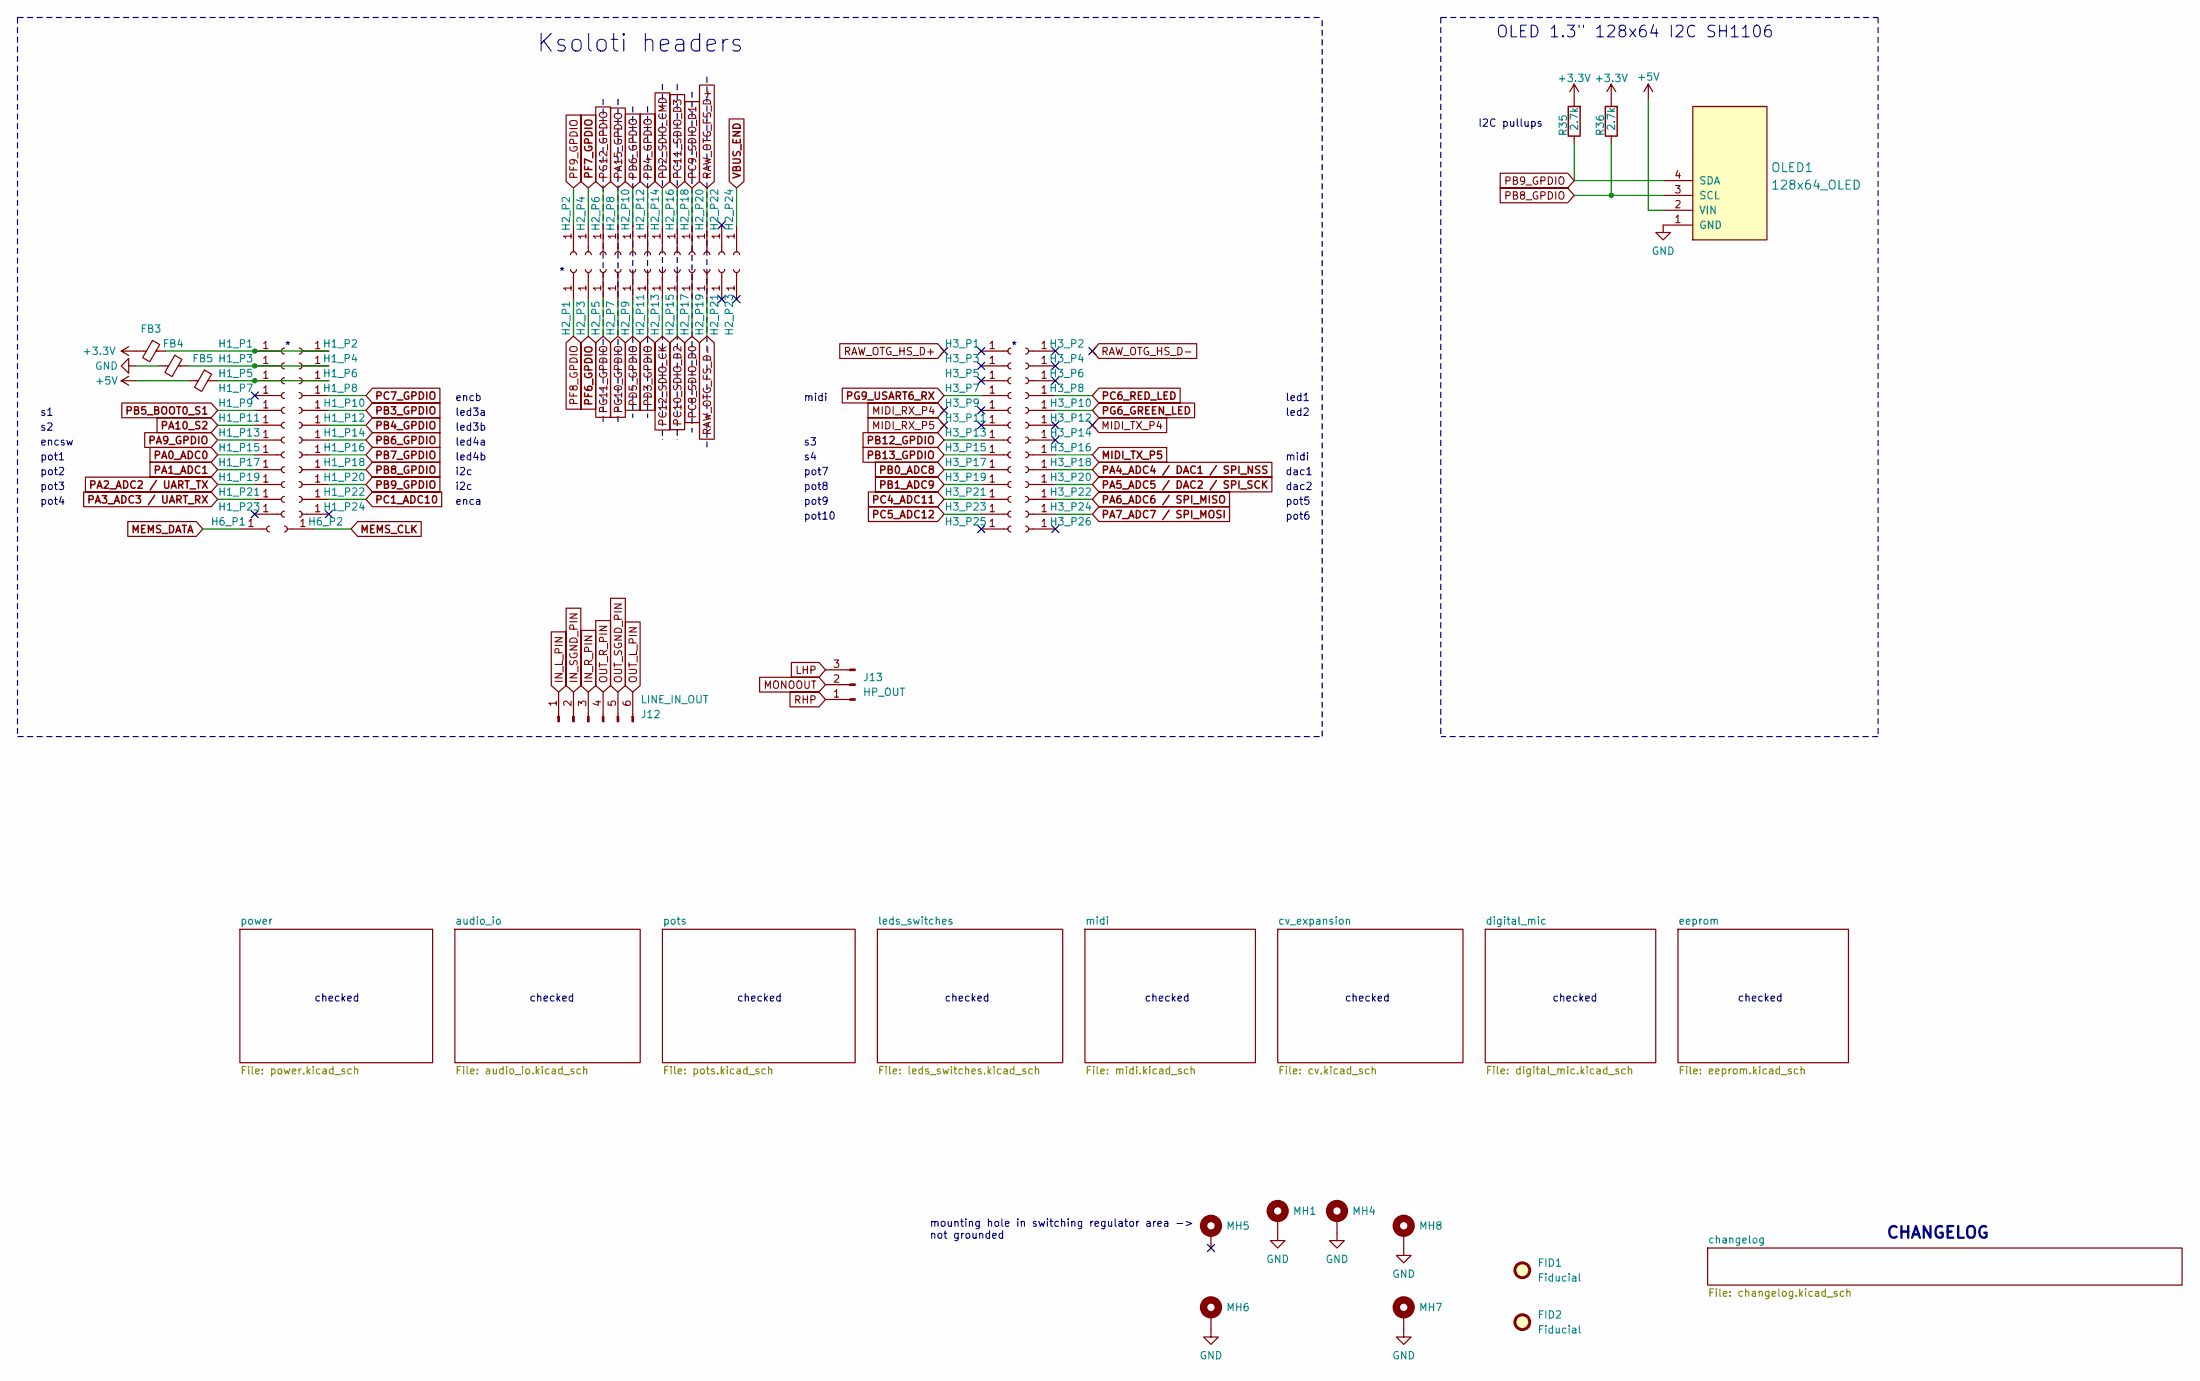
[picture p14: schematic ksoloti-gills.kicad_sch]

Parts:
FB3, FB4, FB5: 100 ohm @ 100 Mhz; R_1206_3216Metric
FID1, FID2: Fiducial; jlc_tooling_hole
H1_P1, H2_P1, H3_P1: Conn_01x01_Female; PinSocket_1x01_P2.54mm_Vertical_smcrt_sqr
H1_P2, H1_P3, H1_P4, H1_P5, H1_P6, H1_P7, H1_P8, H1_P9, H1_P10, H1_P11, H1_P12, H1_P13, H1_P14, H1_P15, H1_P16, H1_P17, H1_P18, H1_P19, H1_P20, H1_P21, H1_P22, H1_P23, H1_P24, H2_P2, H2_P3, H2_P4, H2_P21, H2_P22, H2_P23, H2_P24, H3_P2, H3_P3, H3_P4, H3_P5, H3_P6, H3_P7, H3_P8, H3_P9, H3_P10, H3_P11, H3_P12, H3_P13, H3_P14, H3_P15, H3_P16, H3_P17, H3_P18, H3_P19, H3_P20, H3_P21, H3_P22, H3_P23, H3_P24: Conn_01x01_Female; PinSocket_1x01_P2.54mm_Vertical_smcrt_round
H2_P5, H2_P6, H2_P7, H2_P8, H2_P9, H2_P10, H2_P11, H2_P12, H2_P13, H2_P14, H2_P15, H2_P16, H2_P17, H2_P18, H2_P19, H2_P20, H3_P25, H3_P26: Conn_01x01_Female; PinHeader_1x01_P2.54mm_Vertical_smcrt_round
H6_P1: DMIC_DAT; PinSocket_1x01_P2.54mm_Vertical_smcrt_round
H6_P2: DMIC_CLK; PinSocket_1x01_P2.54mm_Vertical_smcrt_round
J12: LINE_IN_OUT; PinSocket_1x06_P2.54mm_Vertical
J13: HP_OUT; PinSocket_1x03_P2.54mm_Vertical
MH1, MH4, MH5, MH6, MH7, MH8: MountingHole; MountingHole_3.2mm_M3_Pad_Via_tight
OLED1: 128x64_OLED; 128x64OLED_1_3in
R35, R36: 2.7k; R_0603_1608Metric

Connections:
+3.3V: FB3.2, R35.2, R36.2; also elsewhere on the board
+5V: FB5.2, OLED1.2 (VIN); also elsewhere on the board
GND: FB4.2, MH1.1, MH4.1, MH6.1, MH7.1, MH8.1, OLED1.1 (GND); also elsewhere on the board
IN_L_PIN: J12.1; also elsewhere on the board
IN_R_PIN: J12.3; also elsewhere on the board
IN_SGND_PIN: J12.2; also elsewhere on the board
LHP: J13.3; also elsewhere on the board
MEMS_CLK: H6_P2.1; also elsewhere on the board
MEMS_DATA: H6_P1.1; also elsewhere on the board
MIDI_TX_P5: H3_P16.1; also elsewhere on the board
MONOOUT: J13.2; also elsewhere on the board
unnamed: FB3.1, H1_P1.1, H1_P2.1
unnamed: FB4.1, H1_P3.1, H1_P4.1
unnamed: FB5.1, H1_P5.1, H1_P6.1
OUT_L_PIN: J12.6; also elsewhere on the board
OUT_R_PIN: J12.4; also elsewhere on the board
OUT_SGND_PIN: J12.5; also elsewhere on the board
PA0_ADC0: H1_P15.1; also elsewhere on the board
PA1_ADC1: H1_P17.1; also elsewhere on the board
PA2_ADC2 / UART_TX: H1_P19.1; also elsewhere on the board
PA3_ADC3 / UART_RX: H1_P21.1; also elsewhere on the board
PA4_ADC4 / DAC1 / SPI_NSS: H3_P18.1; also elsewhere on the board
PA5_ADC5 / DAC2 / SPI_SCK: H3_P20.1; also elsewhere on the board
PA6_ADC6 / SPI_MISO: H3_P22.1; also elsewhere on the board
PA7_ADC7 / SPI_MOSI: H3_P24.1; also elsewhere on the board
PA9_GPDIO: H1_P13.1; also elsewhere on the board
PA10_S2: H1_P11.1; also elsewhere on the board
PB0_ADC8: H3_P17.1; also elsewhere on the board
PB1_ADC9: H3_P19.1; also elsewhere on the board
PB3_GPDIO: H1_P10.1; also elsewhere on the board
PB4_GPDIO: H1_P12.1; also elsewhere on the board
PB5_BOOT0_S1: H1_P9.1; also elsewhere on the board
PB6_GPDIO: H1_P14.1; also elsewhere on the board
PB7_GPDIO: H1_P16.1; also elsewhere on the board
PB8_GPDIO: H1_P18.1, OLED1.3 (SCL), R36.1; also elsewhere on the board
PB9_GPDIO: H1_P20.1, OLED1.4 (SDA), R35.1; also elsewhere on the board
PB12_GPDIO: H3_P13.1; also elsewhere on the board
PB13_GPDIO: H3_P15.1; also elsewhere on the board
PC1_ADC10: H1_P22.1; also elsewhere on the board
PC4_ADC11: H3_P21.1; also elsewhere on the board
PC5_ADC12: H3_P23.1; also elsewhere on the board
PC6_RED_LED: H3_P8.1; also elsewhere on the board
PC7_GPDIO: H1_P8.1; also elsewhere on the board
PF6_GPDIO: H2_P3.1; also elsewhere on the board
PF7_GPDIO: H2_P4.1; also elsewhere on the board
PF8_GPDIO: H2_P1.1
PF9_GPDIO: H2_P2.1
PG6_GREEN_LED: H3_P10.1; also elsewhere on the board
PG9_USART6_RX: H3_P7.1; also elsewhere on the board
RHP: J13.1; also elsewhere on the board
VBUS_END: H2_P24.1; also elsewhere on the board

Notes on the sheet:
checked
dac2
i2c
led2
led3a
led3b
mounting hole in switching regulator area -> not grounded
led1
encb
pot10
encsw
midi
pot5
pot1
OLED 1.3" 128x64 I2C SH1106
pot8
I2C pullups
Ksoloti headers
pot2
CHANGELOG
led4b
pot7
led4a
pot6
enca
pot3
pot4
pot9
dac1

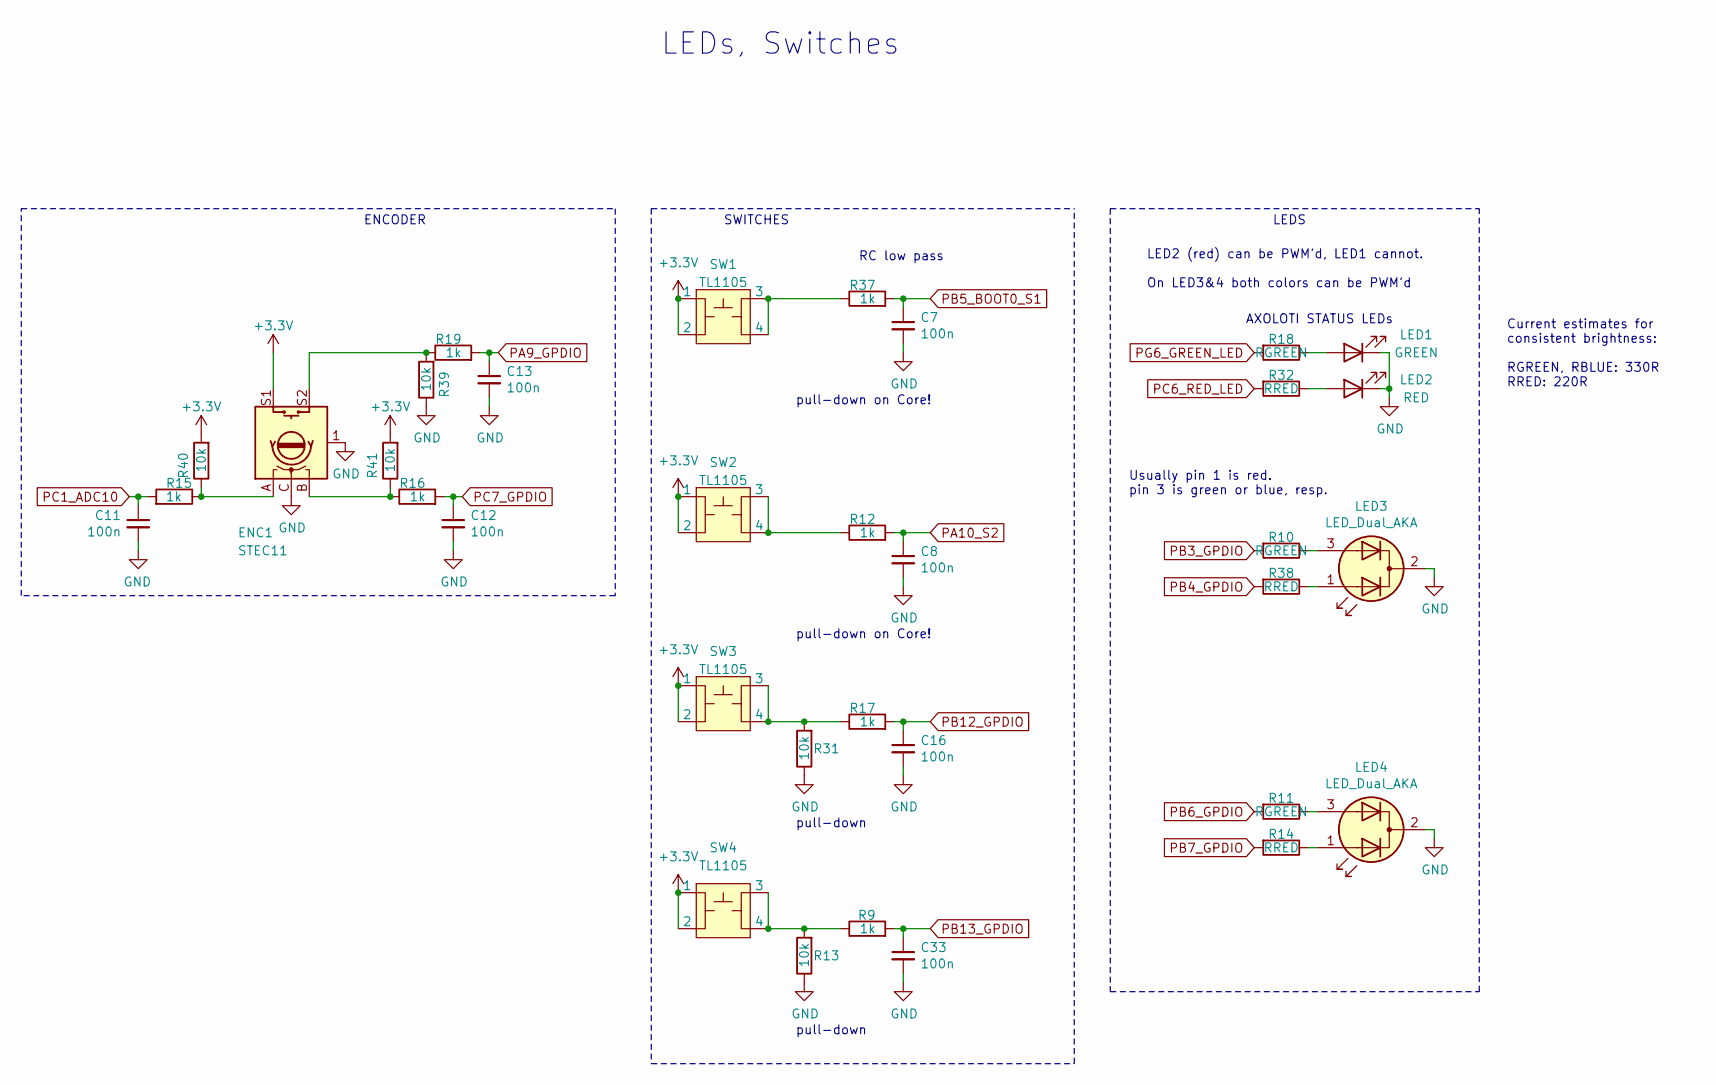
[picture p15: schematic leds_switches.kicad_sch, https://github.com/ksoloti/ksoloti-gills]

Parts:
C7, C8, C11, C12, C13, C16, C33: 100n; C_0603_1608Metric
ENC1: STEC11; ALPS_STEC12E08
LED1: GREEN; LED_D3.0mm_marked
LED2: RED; LED_D3.0mm_marked
LED3, LED4: LED_Dual_AKA; LED_D3.0mm-3_marked
R9, R12, R15, R16, R17, R19, R37: 1k; R_0603_1608Metric
R10, R11, R18: RGREEN; R_0805_2012Metric
R13, R31, R39, R40, R41: 10k; R_0603_1608Metric
R14, R32, R38: RRED; R_0805_2012Metric
SW1, SW2, SW3, SW4: TL1105; TL1105T

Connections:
+3.3V: ENC1.S1, R40.2, R41.2, SW1.1, SW1.2, SW2.1, SW2.2, SW3.1, SW3.2, SW4.1, SW4.2; also elsewhere on the board
GND: C7.2, C8.2, C11.2, C12.2, C13.2, C16.2, C33.2, ENC1.1, ENC1.C, LED1.1 (K), LED2.1 (K), LED3.2 (K), LED4.2 (K), R13.1, R31.1, R39.1; also elsewhere on the board
unnamed: ENC1.A, R15.1, R40.1
unnamed: ENC1.B, R16.1, R41.1
unnamed: ENC1.S2, R19.1, R39.2
unnamed: LED1.2 (A), R18.1
unnamed: LED2.2 (A), R32.1
unnamed: LED3.1 (A1), R38.1
unnamed: LED3.3 (A2), R10.1
unnamed: LED4.1 (A1), R14.1
unnamed: LED4.3 (A2), R11.1
unnamed: R12.1, SW2.3, SW2.4
unnamed: R9.1, R13.2, SW4.3, SW4.4
unnamed: R17.1, R31.2, SW3.3, SW3.4
unnamed: R37.1, SW1.3, SW1.4
PA9_GPDIO: C13.1, R19.2; also elsewhere on the board
PA10_S2: C8.1, R12.2; also elsewhere on the board
PB3_GPDIO: R10.2; also elsewhere on the board
PB4_GPDIO: R38.2; also elsewhere on the board
PB5_BOOT0_S1: C7.1, R37.2; also elsewhere on the board
PB6_GPDIO: R11.2; also elsewhere on the board
PB7_GPDIO: R14.2; also elsewhere on the board
PB12_GPDIO: C16.1, R17.2; also elsewhere on the board
PB13_GPDIO: C33.1, R9.2; also elsewhere on the board
PC1_ADC10: C11.1, R15.2; also elsewhere on the board
PC6_RED_LED: R32.2; also elsewhere on the board
PC7_GPDIO: C12.1, R16.2; also elsewhere on the board
PG6_GREEN_LED: R18.2; also elsewhere on the board

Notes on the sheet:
ENCODER
SWITCHES
pull-down on Core!
LEDS
LED2 (red) can be PWM'd, LED1 cannot. On LED3&4 both colors can be PWM'd
LEDs, Switches
Current estimates for consistent brightness: RGREEN, RBLUE: 330R RRED: 220R
Usually pin 1 is red. pin 3 is green or blue, resp.
pull-down
AXOLOTI STATUS LEDs
RC low pass

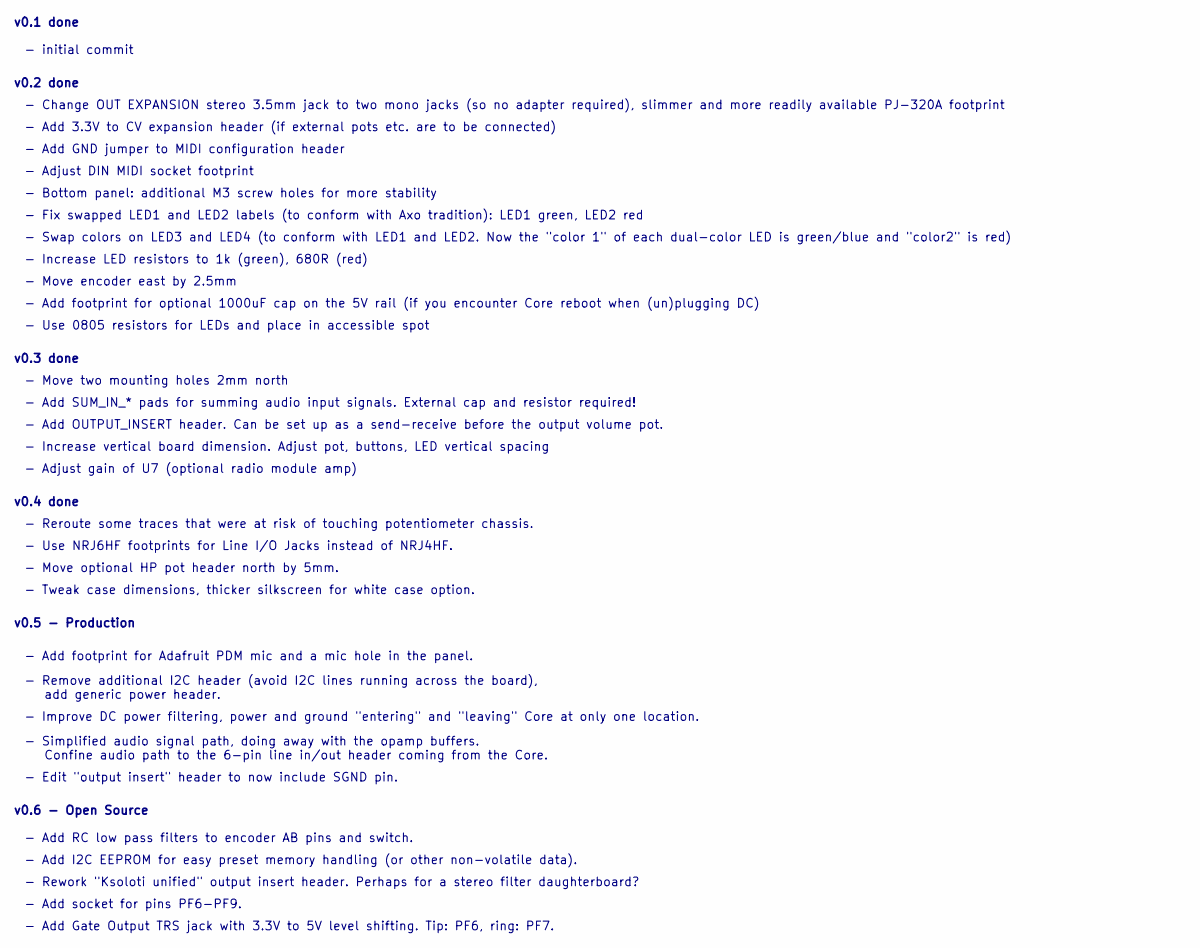
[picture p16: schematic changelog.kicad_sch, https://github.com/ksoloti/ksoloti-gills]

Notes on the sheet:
- Rework "Ksoloti unified" output insert header. Perhaps for a stereo filter daughterboard?
- Use NRJ6HF footprints for Line I/O Jacks instead of NRJ4HF.
- initial commit
v0.5 - Production
v0.2 done
- Tweak case dimensions, thicker silkscreen for white case option.
- Change OUT EXPANSION stereo 3.5mm jack to two mono jacks (so no adapter required), slimmer and more readily available PJ-320A footprint
- Add I2C EEPROM for easy preset memory handling (or other non-volatile data).
- Move encoder east by 2.5mm
- Move optional HP pot header north by 5mm.
- Add footprint for Adafruit PDM mic and a mic hole in the panel.
- Add Gate Output TRS jack with 3.3V to 5V level shifting. Tip: PF6, ring: PF7.
- Add GND jumper to MIDI configuration header
- Remove additional I2C header (avoid I2C lines running across the board), add generic power header.
- Increase vertical board dimension. Adjust pot, buttons, LED vertical spacing
- Move two mounting holes 2mm north
- Fix swapped LED1 and LED2 labels (to conform with Axo tradition): LED1 green, LED2 red
- Adjust DIN MIDI socket footprint
- Add footprint for optional 1000uF cap on the 5V rail (if you encounter Core reboot when (un)plugging DC)
- Add socket for pins PF6-PF9.
v0.6 - Open Source
- Edit "output insert" header to now include SGND pin.
- Simplified audio signal path, doing away with the opamp buffers. Confine audio path to the 6-pin line in/out header coming from the Core.
- Increase LED resistors to 1k (green), 680R (red)
- Swap colors on LED3 and LED4 (to conform with LED1 and LED2. Now the "color 1" of each dual-color LED is green/blue and "color2" is red)
- Improve DC power filtering, power and ground "entering" and "leaving" Core at only one location.
v0.4 done
v0.1 done
- Add SUM_IN_* pads for summing audio input signals. External cap and resistor required!
- Adjust gain of U7 (optional radio module amp)
v0.3 done
- Bottom panel: additional M3 screw holes for more stability
- Add 3.3V to CV expansion header (if external pots etc. are to be connected)
- Add OUTPUT_INSERT header. Can be set up as a send-receive before the output volume pot.
- Reroute some traces that were at risk of touching potentiometer chassis.
- Use 0805 resistors for LEDs and place in accessible spot
- Add RC low pass filters to encoder AB pins and switch.

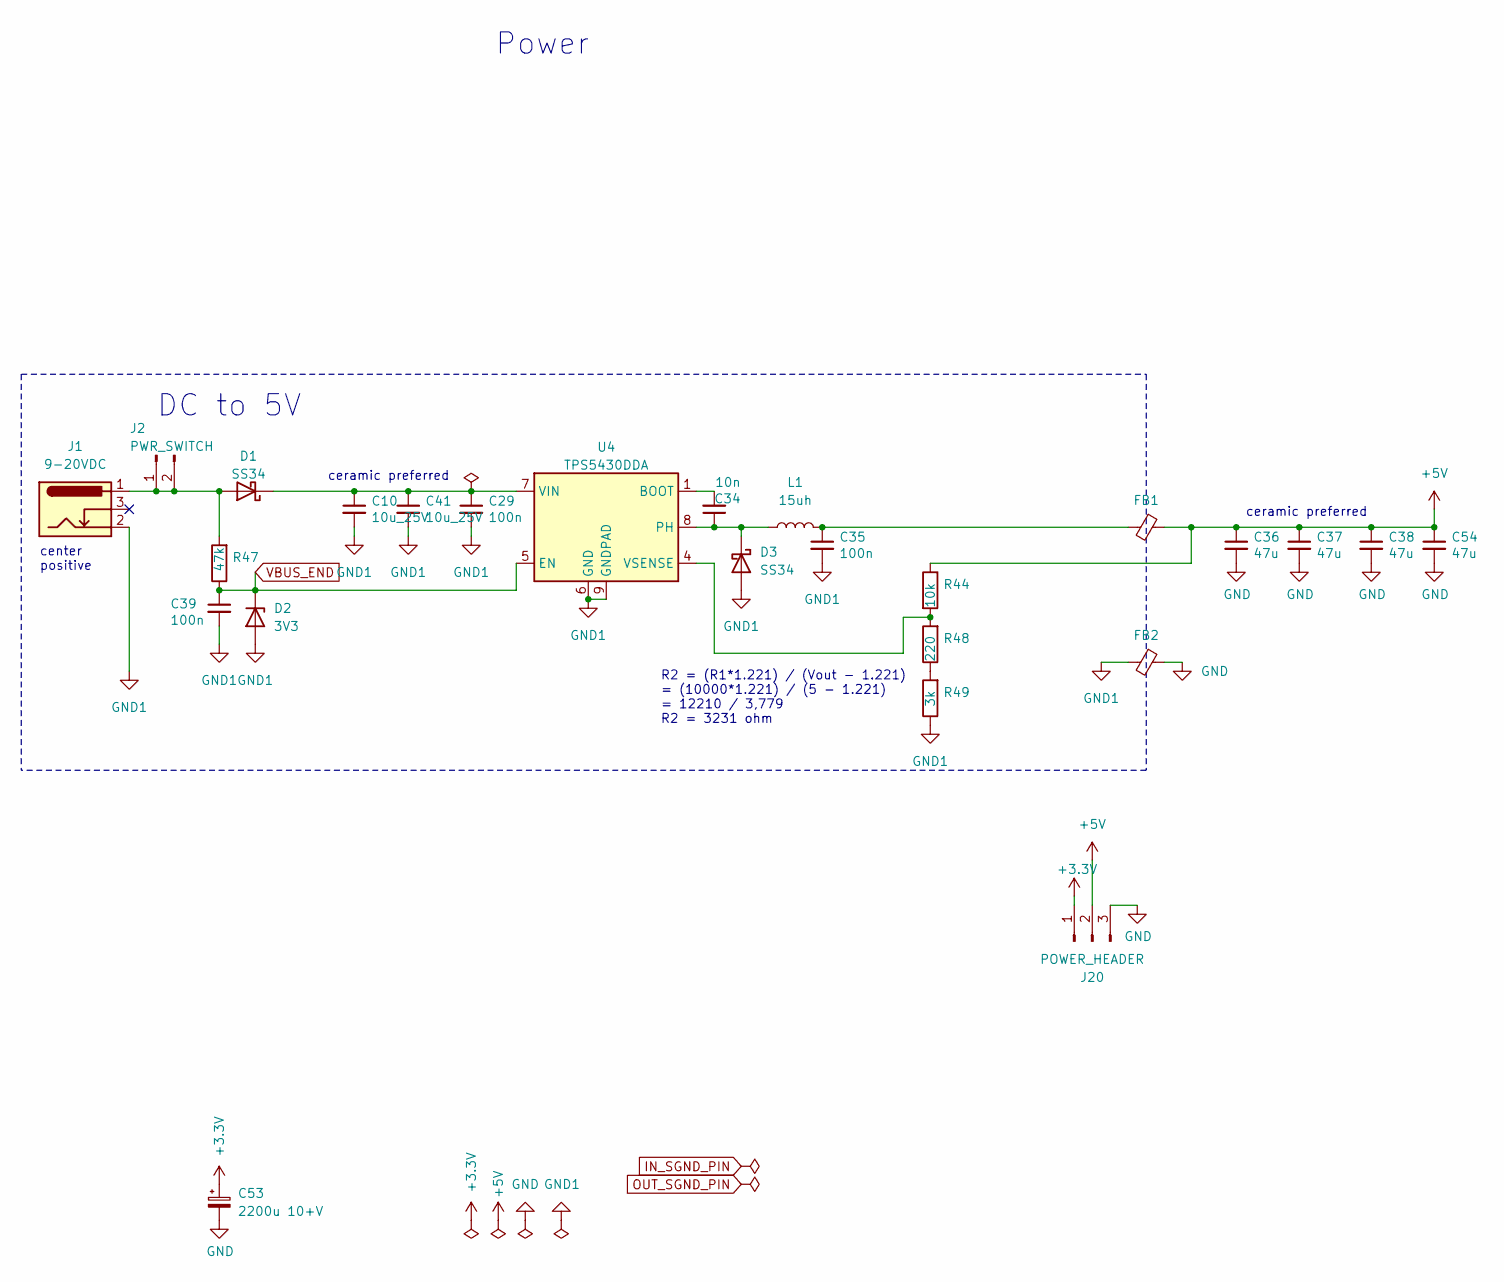
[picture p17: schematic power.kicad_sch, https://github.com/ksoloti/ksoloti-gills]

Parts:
C10, C41: 10u_25V; C_0603_1608Metric
C29, C35, C39: 100n; C_0603_1608Metric
C34: 10n; C_0603_1608Metric
C36, C37, C38, C54: 47u; C_1206_3216Metric
C53: 2200u 10+V; CP_Radial_D10.0mm_P5.00mm
D1, D3: SS34; D_SMA
D2: 3V3; D_MiniMELF
FB1, FB2: 100 ohm @ 100 Mhz; R_1206_3216Metric
J1: 9-20VDC; dc_socket
J2: PWR_SWITCH; PinHeader_1x02_P2.54mm_Vertical
J20: POWER_HEADER; PinHeader_1x03_P2.54mm_Vertical
L1: 15uh; L_7.3x6.7_H3.5
R44: 10k; R_0603_1608Metric
R47: 47k; R_0603_1608Metric
R48: 220; R_0603_1608Metric
R49: 3k; R_0603_1608Metric
U4: TPS5430DDA; TI_SO-PowerPAD-8_ThermalVias

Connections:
+3.3V: C53.1, J20.1; also elsewhere on the board
+5V: C36.1, C37.1, C38.1, C54.1, FB1.1, J20.2, R44.1; also elsewhere on the board
GND: C36.2, C37.2, C38.2, C53.2, C54.2, FB2.1, J20.3; also elsewhere on the board
GND1: C10.2, C29.2, C35.2, C39.2, C41.2, D2.2 (A), D3.2 (A), FB2.2, J1.2, R49.1, U4.6 (GND), U4.9 (GNDPAD)
unnamed: C35.1, FB1.2, L1.2
unnamed: D1.2 (A), J1.1, J2.1, J2.2, R47.2
unnamed: C10.1, C29.1, C41.1, D1.1 (K), U4.7 (VIN)
unnamed: C34.1, D3.1 (K), L1.1, U4.8 (PH)
unnamed: R48.1, R49.2
unnamed: C34.2, U4.1 (BOOT)
unnamed: R44.2, R48.2, U4.4 (VSENSE)
VBUS_END: C39.1, D2.1 (K), R47.1, U4.5 (EN); also elsewhere on the board

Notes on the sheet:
Power
DC to 5V
center positive
ceramic preferred
R2 = (R1*1.221) / (Vout - 1.221) = (10000*1.221) / (5 - 1.221) = 12210 / 3,779 R2 = 3231 ohm

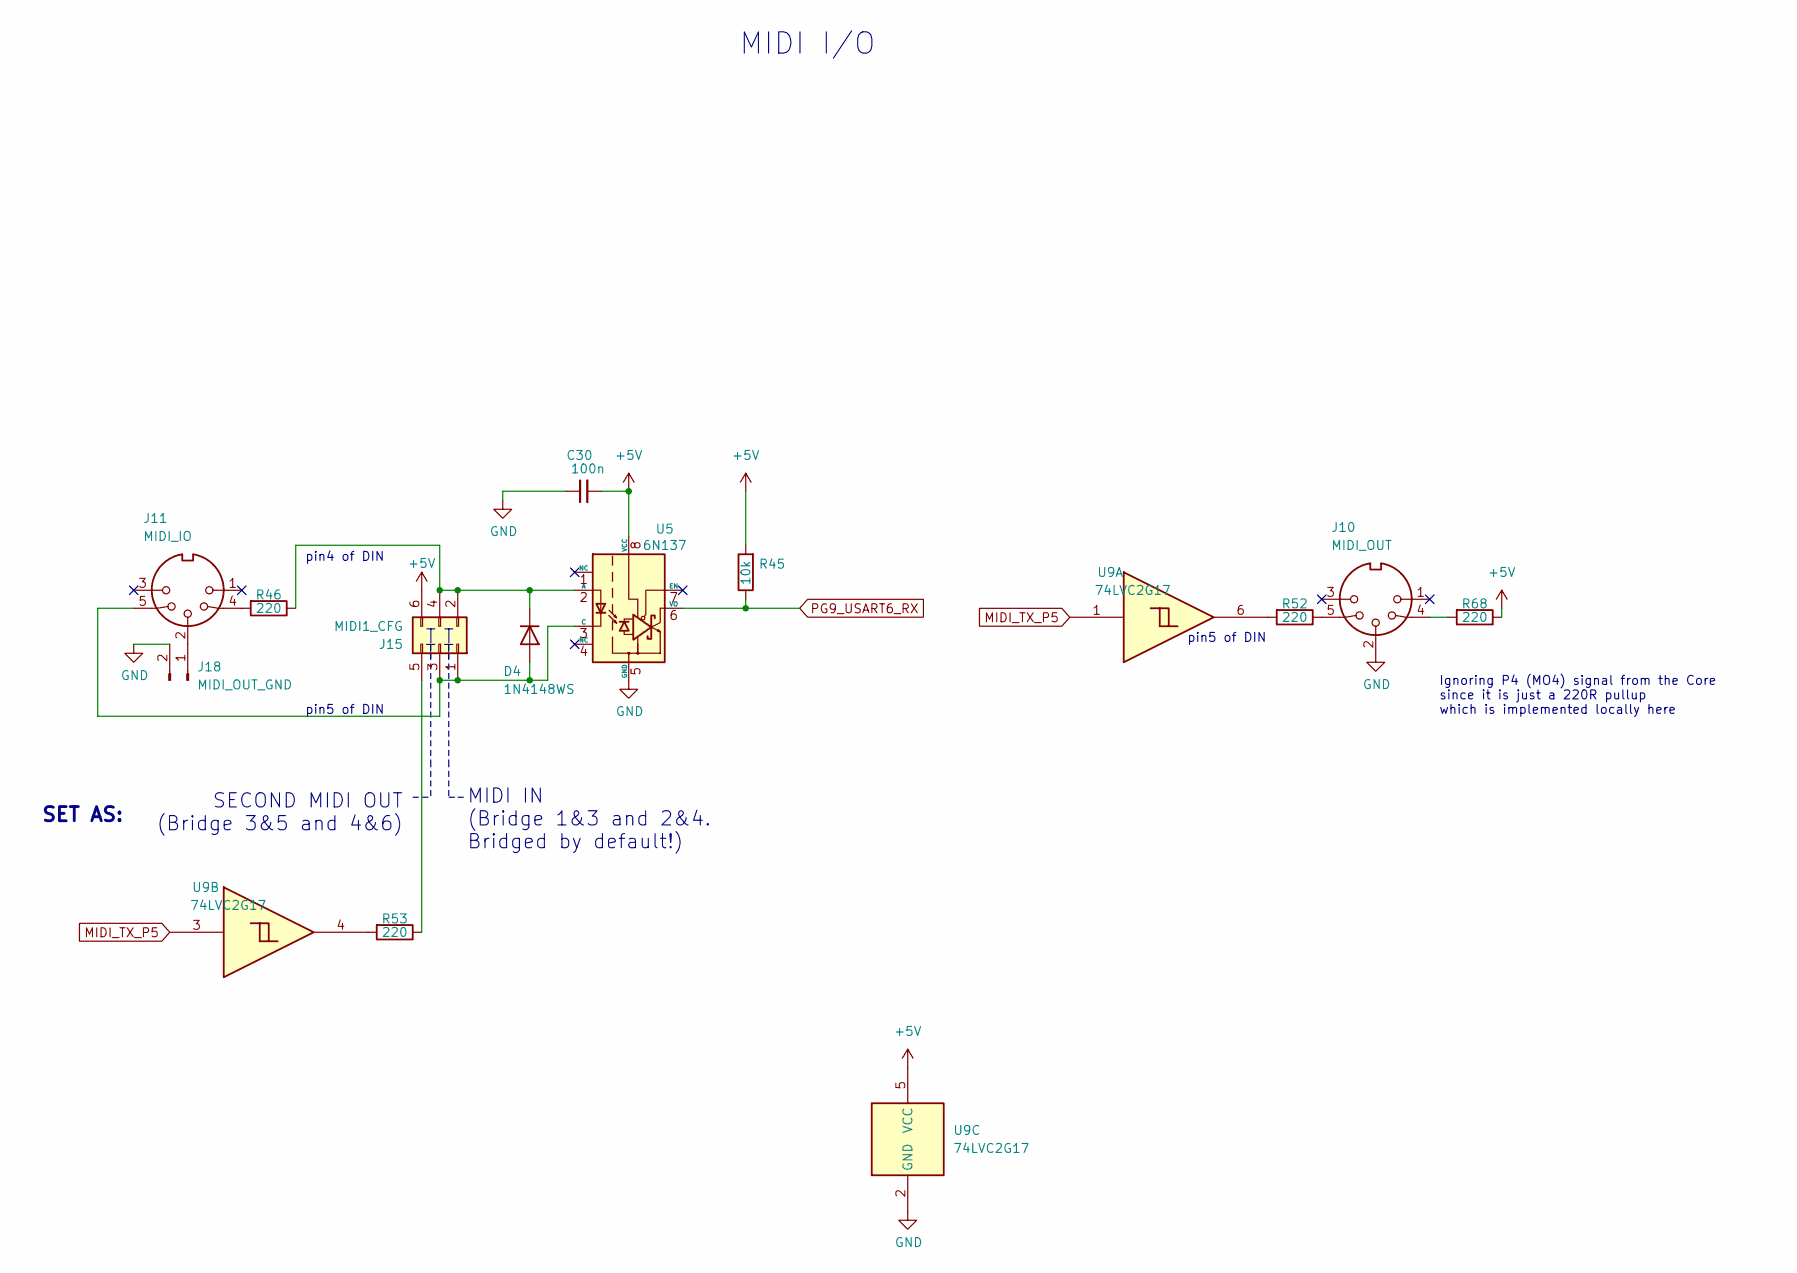
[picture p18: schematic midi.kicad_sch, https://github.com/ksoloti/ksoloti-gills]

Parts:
C30: 100n; C_0603_1608Metric
D4: 1N4148WS; D_SOD-323
J10: MIDI_OUT; MIDI_DIN-5_DS-5-01c
J11: MIDI_IO; MIDI_DIN-5_DS-5-01c
J15: MIDI1_CFG; PinHeader_2x03_P2.54mm_Vertical
J18: MIDI_OUT_GND; PinHeader_1x02_P2.54mm_Vertical
R45: 10k; R_0603_1608Metric
R46, R52, R53, R68: 220; R_0603_1608Metric
U5: 6N137; SMDIP-8_W9.53mm
U9: 74LVC2G17; SOT-23-6

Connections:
+5V: C30.2, J15.6, R45.2, R68.1, U5.8 (VCC), U9.5 (VCC); also elsewhere on the board
GND: C30.1, J10.2, J18.2, U5.5 (GND), U9.2 (GND); also elsewhere on the board
MIDI_TX_P5: U9.1, U9.3; also elsewhere on the board
unnamed: D4.2 (A), J11.5, J15.1, J15.3, U5.3 (C)
unnamed: D4.1 (K), J15.2, J15.4, R46.1, U5.2 (A)
unnamed: J10.4, R68.2
unnamed: J10.5, R52.1
unnamed: J11.4, R46.2
unnamed: J15.5, R53.1
unnamed: J11.2, J18.1
unnamed: R52.2, U9.6
unnamed: R53.2, U9.4
PG9_USART6_RX: R45.1, U5.6 (VO); also elsewhere on the board

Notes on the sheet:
Ignoring P4 (MO4) signal from the Core since it is just a 220R pullup which is implemented locally here
MIDI IN (Bridge 1&3 and 2&4. Bridged by default!)
pin4 of DIN
pin5 of DIN
MIDI I/O
SECOND MIDI OUT (Bridge 3&5 and 4&6)
SET AS:

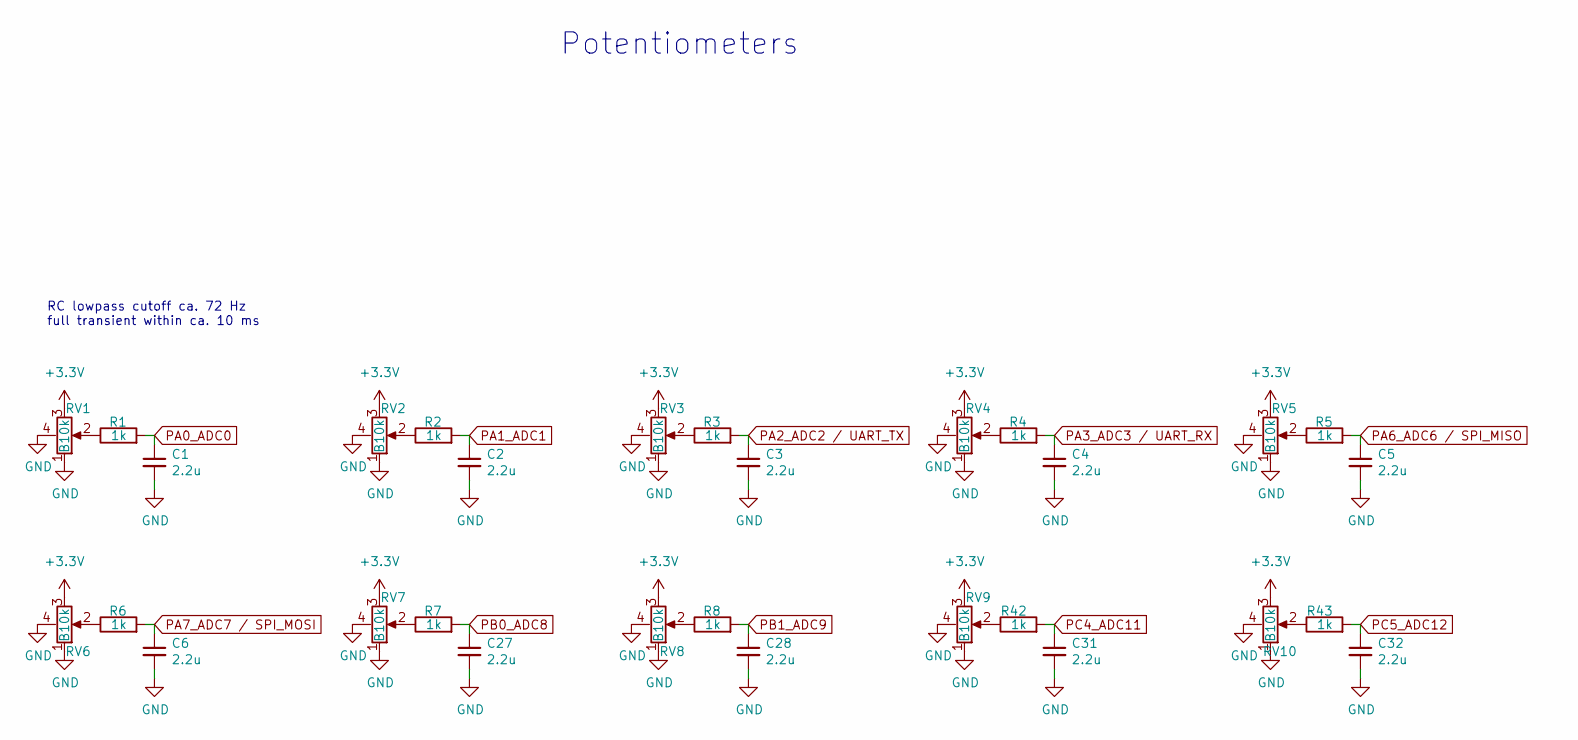
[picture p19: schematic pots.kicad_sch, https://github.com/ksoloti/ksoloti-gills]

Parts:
C1, C2, C3, C4, C5, C6, C27, C28, C31, C32: 2.2u; C_0603_1608Metric
R1, R2, R3, R4, R5, R6, R7, R8, R42, R43: 1k; R_0603_1608Metric
RV1, RV2, RV3, RV4, RV5, RV6, RV7, RV8, RV9, RV10: B10k; ALPS_POT_VERTICAL_PS

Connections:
+3.3V: RV1.3, RV2.3, RV3.3, RV4.3, RV5.3, RV6.3, RV7.3, RV8.3, RV9.3, RV10.3; also elsewhere on the board
GND: C1.2, C2.2, C3.2, C4.2, C5.2, C6.2, C27.2, C28.2, C31.2, C32.2, RV1.1, RV1.4, RV2.1, RV2.4, RV3.1, RV3.4, RV4.1, RV4.4, RV5.1, RV5.4, RV6.1, RV6.4, RV7.1, RV7.4, RV8.1, RV8.4, RV9.1, RV9.4, RV10.1, RV10.4; also elsewhere on the board
unnamed: R1.1, RV1.2
unnamed: R2.1, RV2.2
unnamed: R3.1, RV3.2
unnamed: R4.1, RV4.2
unnamed: R5.1, RV5.2
unnamed: R6.1, RV6.2
unnamed: R7.1, RV7.2
unnamed: R8.1, RV8.2
unnamed: R42.1, RV9.2
unnamed: R43.1, RV10.2
PA0_ADC0: C1.1, R1.2; also elsewhere on the board
PA1_ADC1: C2.1, R2.2; also elsewhere on the board
PA2_ADC2 / UART_TX: C3.1, R3.2; also elsewhere on the board
PA3_ADC3 / UART_RX: C4.1, R4.2; also elsewhere on the board
PA6_ADC6 / SPI_MISO: C5.1, R5.2; also elsewhere on the board
PA7_ADC7 / SPI_MOSI: C6.1, R6.2; also elsewhere on the board
PB0_ADC8: C27.1, R7.2; also elsewhere on the board
PB1_ADC9: C28.1, R8.2; also elsewhere on the board
PC4_ADC11: C31.1, R42.2; also elsewhere on the board
PC5_ADC12: C32.1, R43.2; also elsewhere on the board

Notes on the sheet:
Potentiometers
RC lowpass cutoff ca. 72 Hz full transient within ca. 10 ms

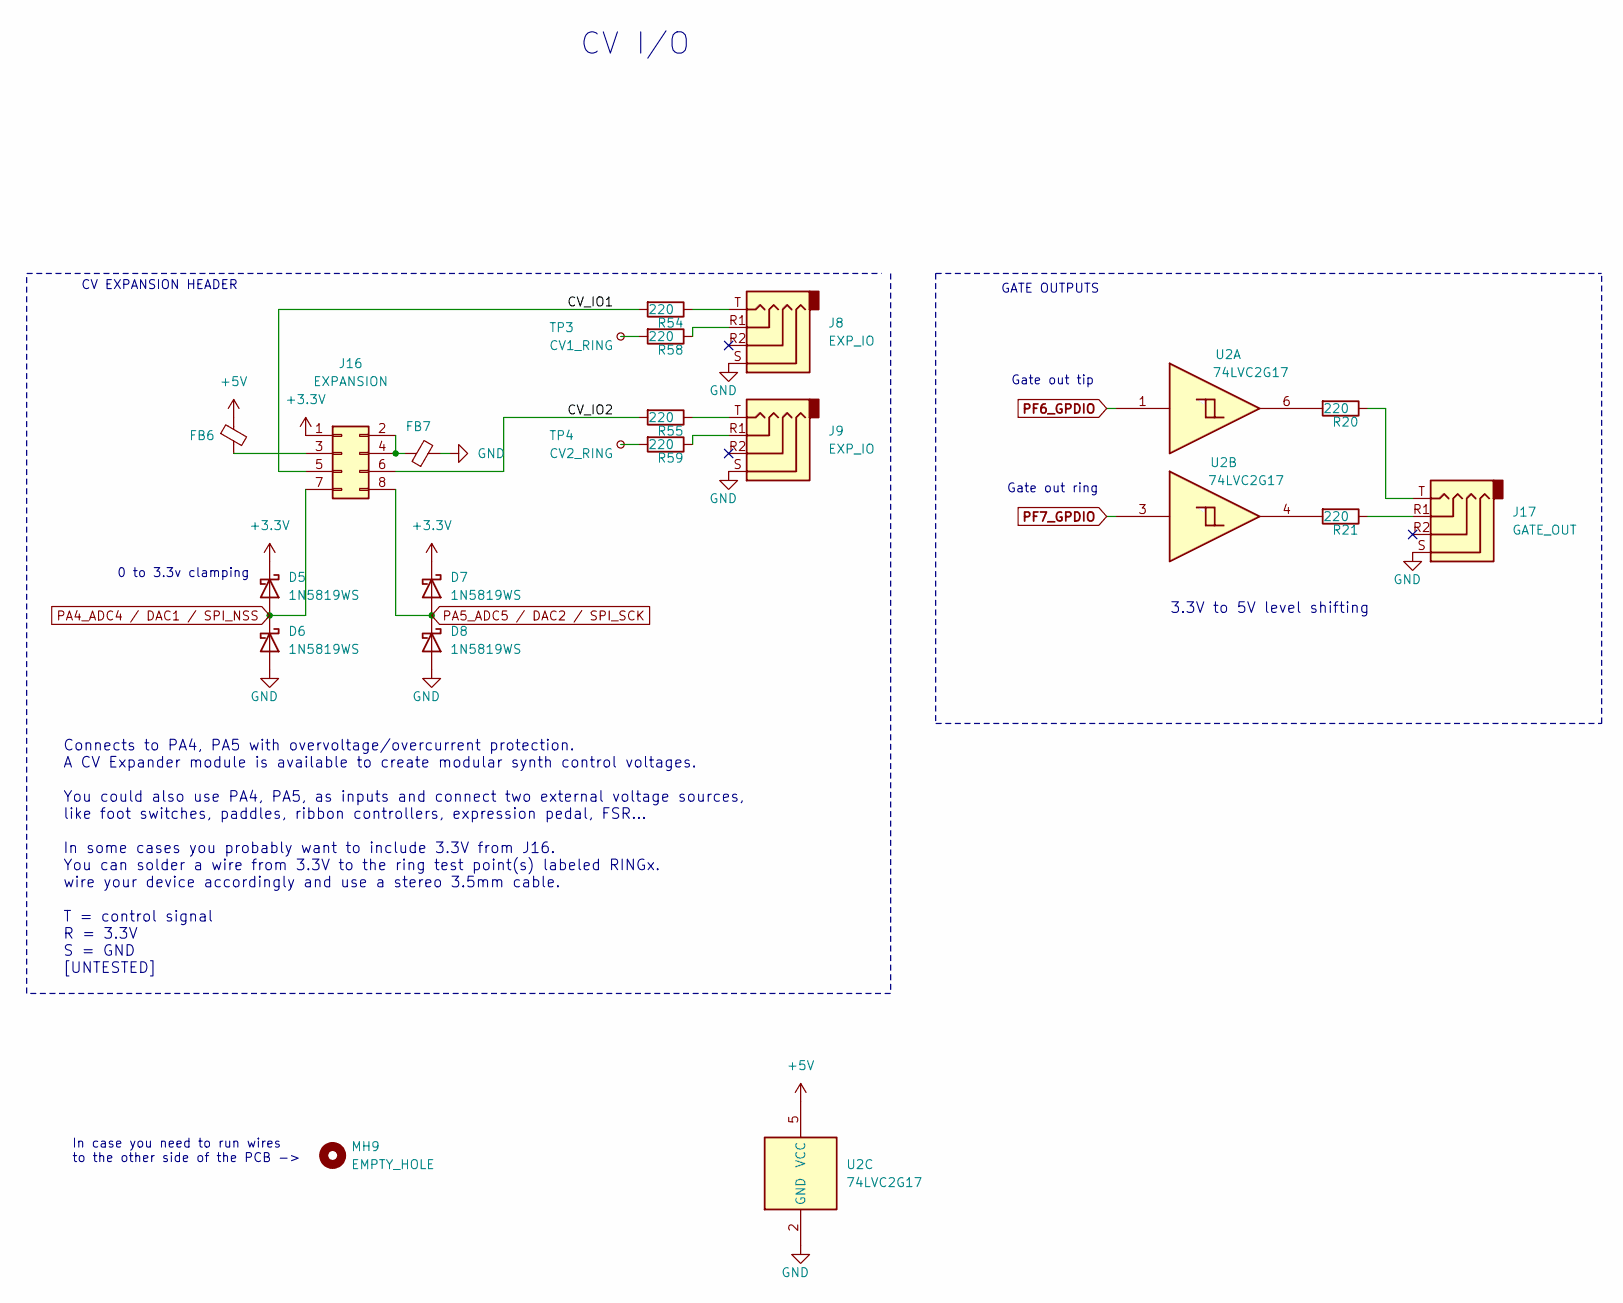
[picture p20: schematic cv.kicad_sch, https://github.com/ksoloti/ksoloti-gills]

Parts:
D5, D6, D7, D8: 1N5819WS; D_SOD-323
FB6, FB7: 100 ohm @ 100 Mhz; R_0805_2012Metric
J8, J9: EXP_IO; PJ-320A_THT
J16: EXPANSION; PinHeader_2x04_P2.54mm_Vertical
J17: GATE_OUT; PJ-320A_THT
MH9: EMPTY_HOLE; MountingHole_6mm
R20, R21, R54, R55, R58, R59: 220; R_0603_1608Metric
TP3: CV1_RING; TestPoint_THTPad_D1.5mm_Drill0.7mm
TP4: CV2_RING; TestPoint_THTPad_D1.5mm_Drill0.7mm
U2: 74LVC2G17; SOT-23-6

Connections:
+3.3V: D5.1 (K), D7.1 (K), J16.1; also elsewhere on the board
+5V: FB6.1, U2.5 (VCC); also elsewhere on the board
/cv_expansion/CV_IO1: J16.5, R54.2
/cv_expansion/CV_IO2: J16.6, R55.2
GND: D6.2 (A), D8.2 (A), FB7.2, J8.S, J9.S, J17.S, U2.2 (GND); also elsewhere on the board
unnamed: J8.R1, R58.1
unnamed: J8.T, R54.1
unnamed: J9.R1, R59.1
unnamed: J9.T, R55.1
unnamed: FB7.1, J16.2, J16.4
unnamed: FB6.2, J16.3
unnamed: J17.R1, R21.1
unnamed: J17.T, R20.1
unnamed: R20.2, U2.6
unnamed: R21.2, U2.4
unnamed: R58.2, TP3.1
unnamed: R59.2, TP4.1
PA4_ADC4 / DAC1 / SPI_NSS: D5.2 (A), D6.1 (K), J16.7; also elsewhere on the board
PA5_ADC5 / DAC2 / SPI_SCK: D7.2 (A), D8.1 (K), J16.8; also elsewhere on the board
PF6_GPDIO: U2.1; also elsewhere on the board
PF7_GPDIO: U2.3; also elsewhere on the board

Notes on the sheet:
In case you need to run wires to the other side of the PCB ->
CV I/O
0 to 3.3v clamping
3.3V to 5V level shifting
GATE OUTPUTS
Connects to PA4, PA5 with overvoltage/overcurrent protection. A CV Expander module is available to create modular synth control voltages. You could also use PA4, PA5, as inputs and connect two external voltage sources, like foot switches, paddles, ribbon controllers, expression pedal, FSR... In som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
Gate out tip
Gate out ring
CV EXPANSION HEADER

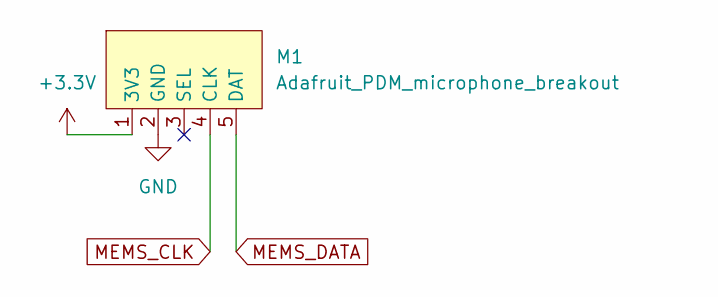
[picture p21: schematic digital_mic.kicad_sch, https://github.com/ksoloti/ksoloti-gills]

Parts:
M1: Adafruit_PDM_microphone_breakout; Adafruit PDM microphone breakout

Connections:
+3.3V: M1.1 (3V3); also elsewhere on the board
GND: M1.2 (GND); also elsewhere on the board
MEMS_CLK: M1.4 (CLK); also elsewhere on the board
MEMS_DATA: M1.5 (DAT); also elsewhere on the board

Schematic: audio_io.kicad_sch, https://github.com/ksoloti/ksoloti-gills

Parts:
J3: IN_L; Jack_6.35mm_Neutrik_NRJ6HF_Horizontal_no_screwhole
J4: IN_R; Jack_6.35mm_Neutrik_NRJ6HF_Horizontal_no_screwhole
J5: OUT_L; Jack_6.35mm_Neutrik_NRJ6HF_Horizontal_no_screwhole
J6: OUT_R; Jack_6.35mm_Neutrik_NRJ6HF_Horizontal_no_screwhole
J7: HP_OUT; Jack_6.35mm_Neutrik_NRJ6HF_Horizontal_no_screwhole
J14: HP_POT; PinHeader_2x03_P2.54mm_Vertical
J19: OUTPUT_INSERT; PinHeader_1x05_P2.54mm_Vertical
JP2: LR_NORMAL; SolderJumper-2_0603_Bridged_0_25mm
R22, R23, R24, R33: 220; R_0603_1608Metric
R25, R34, R56, R57: 47k; R_0603_1608Metric
RV11, RV12: 2*B100k; ALPS_POT_VERTICAL_PS_DUAL
TP1: OUT_L_RING; TestPoint_THTPad_D1.5mm_Drill0.7mm
TP2: OUT_R_RING; TestPoint_THTPad_D1.5mm_Drill0.7mm

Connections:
GND: RV11.7, RV12.7; also elsewhere on the board
IN_L_PIN: R56.2, RV11.2; also elsewhere on the board
IN_R_PIN: R57.2, RV11.5; also elsewhere on the board
IN_SGND_PIN: J3.S, J3.SN, J4.S, J4.SN, R56.1, R57.1, RV11.1, RV11.4; also elsewhere on the board
LHP: J7.T, J14.4, J14.6; also elsewhere on the board
MONOOUT: J7.S, J14.1, J14.2; also elsewhere on the board
unnamed: J4.T, RV11.6
unnamed: J5.R, R22.2
unnamed: J5.T, R23.2
unnamed: J6.R, R24.2
unnamed: J6.T, R33.2
unnamed: J4.TN, JP2.1 (A)
unnamed: J3.T, JP2.2 (B), RV11.3
unnamed: R22.1, TP1.1
unnamed: R23.1, R25.2, RV12.2
unnamed: R24.1, TP2.1
unnamed: R33.1, R34.2, RV12.5
OUT_L_PIN: J19.4, J19.5, RV12.3; also elsewhere on the board
OUT_R_PIN: J19.1, J19.2, RV12.6; also elsewhere on the board
OUT_SGND_PIN: J5.S, J5.SN, J6.S, J6.SN, J19.3, R25.1, R34.1, RV12.1, RV12.4; also elsewhere on the board
RHP: J7.R, J14.3, J14.5; also elsewhere on the board

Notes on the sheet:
R->
L->
HEADPHONES
output attenuator
If installing a headphone volume pot, cut bridges between pins 3&5 and 4&6!
OPTIONAL HP VOLUME
OUTPUT
INPUT
Pot "chassis"
Audio I/O
input attenuator

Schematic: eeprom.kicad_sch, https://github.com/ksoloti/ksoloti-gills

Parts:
C9: 100n; C_0603_1608Metric
U1: M24512; SOIC-8_3.9x4.9mm_P1.27mm

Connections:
+3.3V: C9.1, U1.8 (VCC); also elsewhere on the board
GND: C9.2, U1.1 (E0), U1.2 (E1), U1.3 (E2), U1.4 (VSS), U1.7 (~WC); also elsewhere on the board
PB8_GPDIO: U1.6 (SCL); also elsewhere on the board
PB9_GPDIO: U1.5 (SDA); also elsewhere on the board

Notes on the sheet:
M24512-W SOIC-8

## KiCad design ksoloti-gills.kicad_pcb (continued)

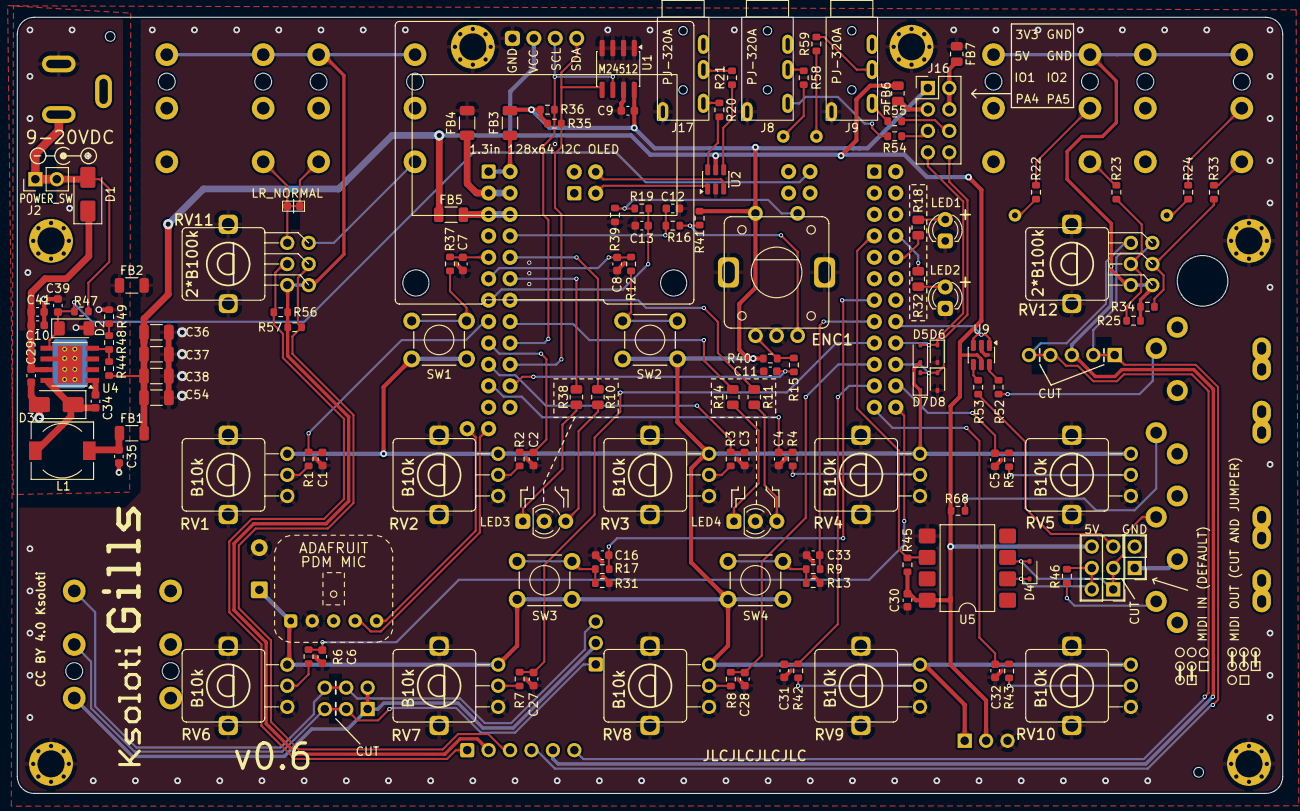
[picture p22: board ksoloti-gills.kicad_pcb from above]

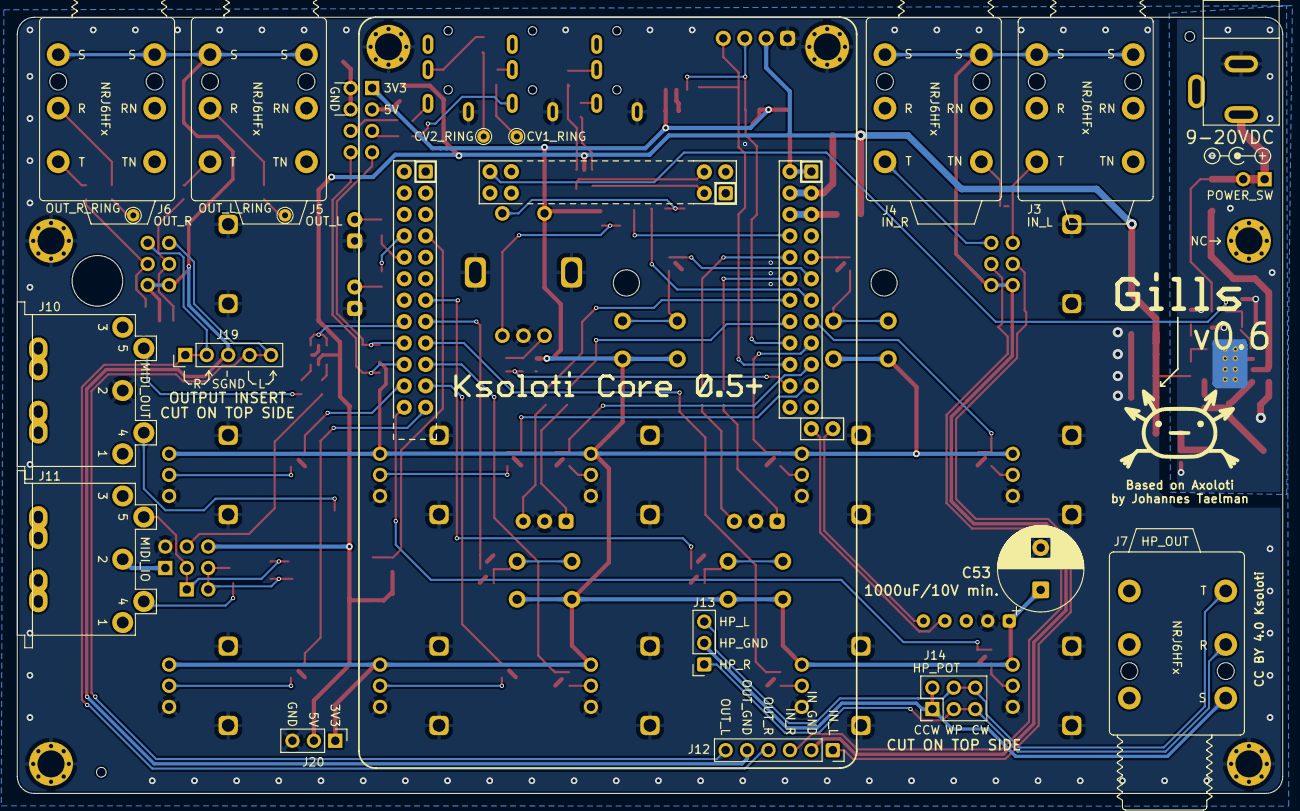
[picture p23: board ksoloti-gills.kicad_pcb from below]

Board: 2 copper layers, 150.0 x 92.0 mm, 224 parts (78 on the bottom side), 114 nets.

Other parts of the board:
DUMMY_CORE_3DMODEL: Symbol_Barrel_Polarity
DUMMY_CV_EXP_3DMODEL: Symbol_Barrel_Polarity
G513513: LOGO
LOGO1, LOGO2: Symbol_Barrel_Polarity

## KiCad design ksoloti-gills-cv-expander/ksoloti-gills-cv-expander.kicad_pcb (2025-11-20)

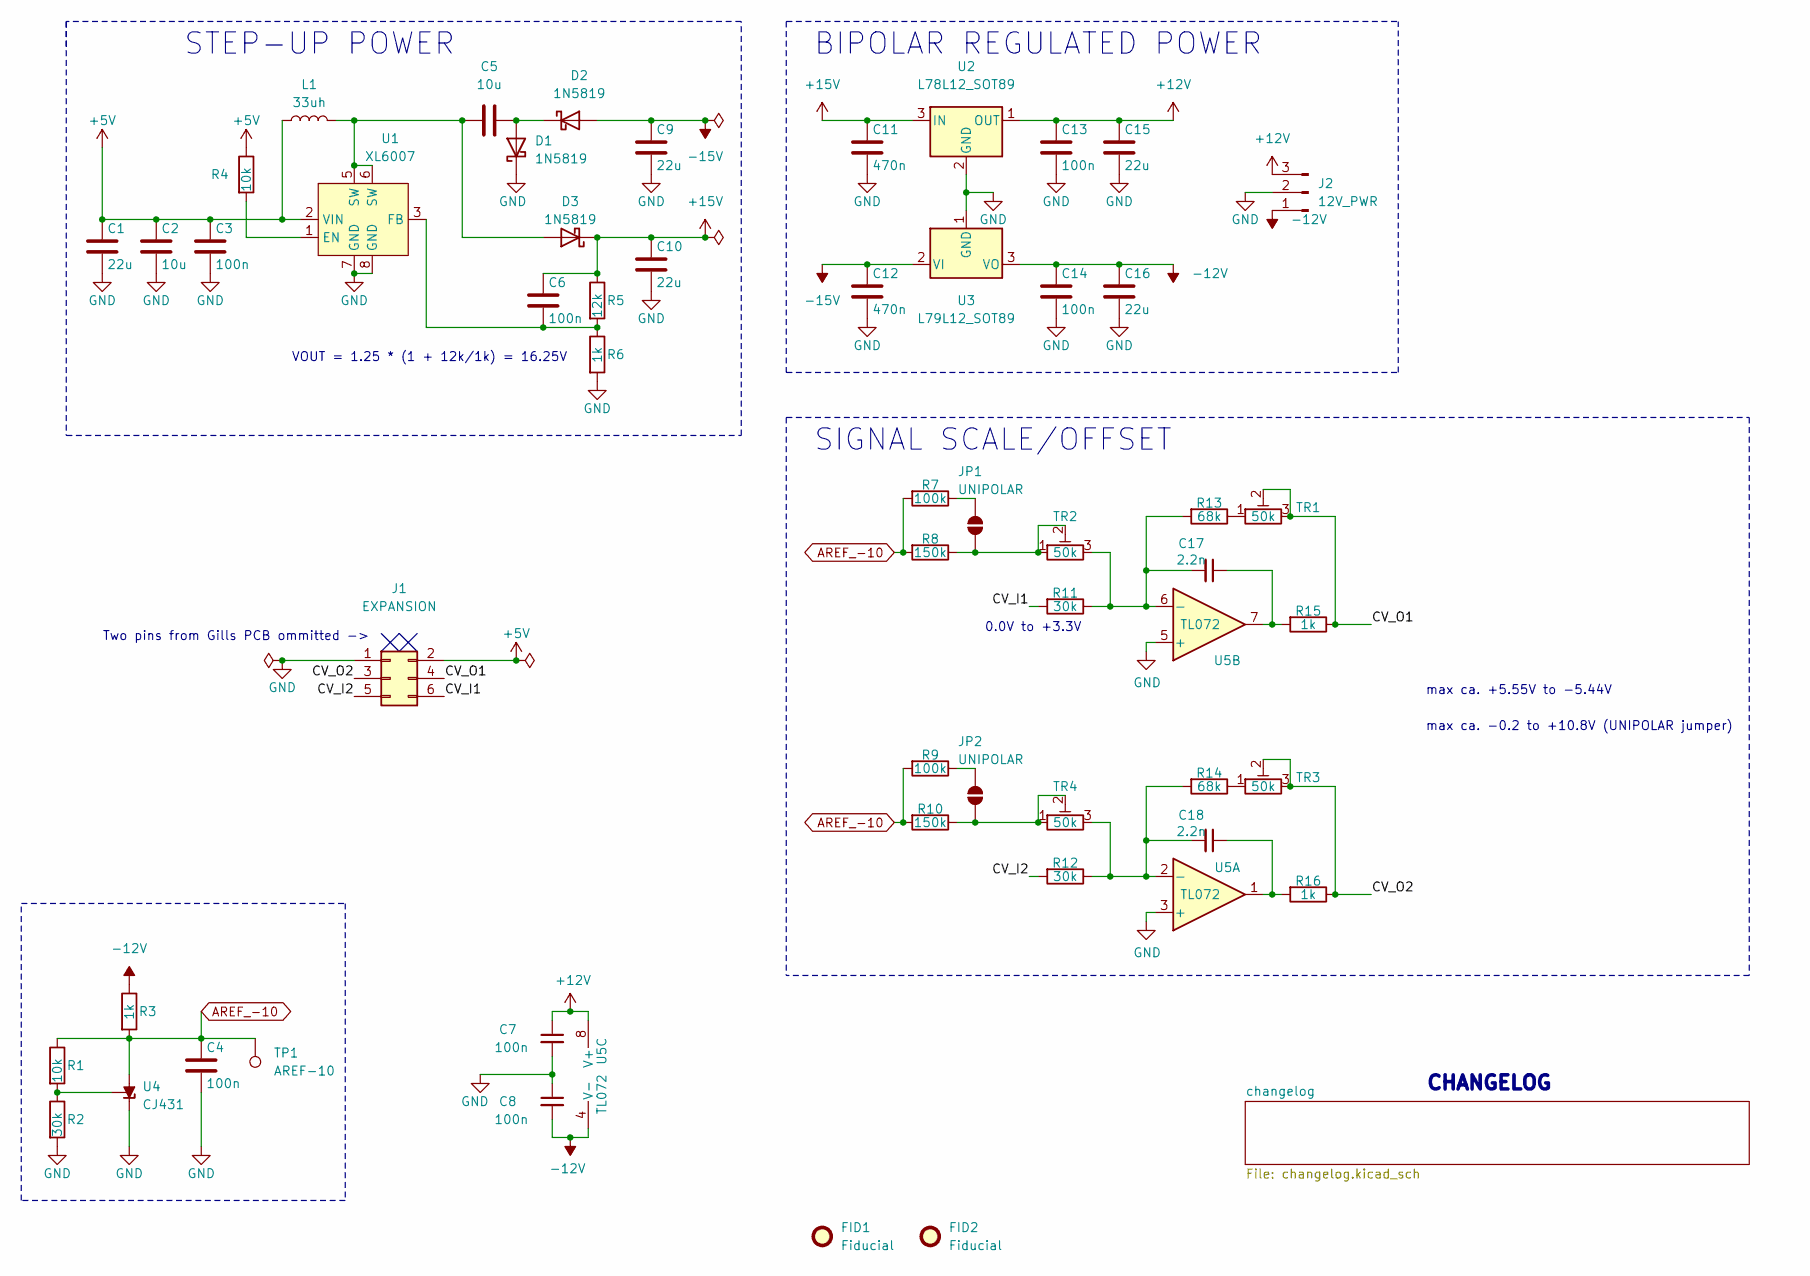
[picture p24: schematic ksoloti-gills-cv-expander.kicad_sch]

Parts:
C1, C9, C10, C15, C16: 22u; C_0805_2012Metric
C2, C5: 10u; C_0603_1608Metric
C3, C4, C6, C7, C8, C13, C14: 100n; C_0603_1608Metric
C11, C12: 470n; C_0603_1608Metric
C17, C18: 2.2n; C_0603_1608Metric
D1, D2, D3: 1N5819; D_SOD-323
FID1, FID2: Fiducial; jlc_tooling_hole
J1: EXPANSION; PinHeader_2x03_P2.54mm_Vertical
J2: 12V_PWR; PinHeader_1x03_P2.54mm_Vertical
JP1, JP2: UNIPOLAR; SolderJumper-2_0603_Open
L1: 33uh; L_APV_ANR5020
R1, R4: 10k; R_0603_1608Metric
R2, R11, R12: 30k; R_0603_1608Metric
R3, R6, R15, R16: 1k; R_0603_1608Metric
R5: 12k; R_0603_1608Metric
R7, R9: 100k; R_0603_1608Metric
R8, R10: 150k; R_0603_1608Metric
R13, R14: 68k; R_0603_1608Metric
TP1: AREF-10; TestPoint_THTPad_D1.0mm_Drill0.5mm
TR1, TR2, TR3, TR4: 50k; Potentiometer_Bourns_3266P_Horizontal
U1: XL6007; SOIC-8-1EP_3.9x4.9mm_P1.27mm_EP2.41x3.81mm
U2: L78L12_SOT89; SOT-89-3_clearance
U3: L79L12_SOT89; SOT-89-3_clearance
U4: CJ431; SOT-23W
U5: TL072; SOIC-8_3.9x4.9mm_P1.27mm

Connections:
+5V: C1.1, C2.1, C3.1, J1.2, L1.1, R4.1, U1.2 (VIN)
+12V: C7.1, C13.1, C15.1, J2.3, U2.1 (OUT), U5.8 (V+)
+15V: C6.1, C10.1, C11.1, D3.1 (K), R5.1, U2.3 (IN)
-12V: C8.2, C14.1, C16.1, J2.1, R3.1, U3.3 (VO), U5.4 (V-)
-15V: C9.1, C12.1, D2.2 (A), U3.2 (VI)
/CV_I1: J1.6, R11.2
/CV_I2: J1.5, R12.2
/CV_O1: J1.4, R15.1, TR1.2, TR1.3
/CV_O2: J1.3, R16.1, TR3.2, TR3.3
AREF_-10: C4.1, R1.1, R3.2, R7.2, R8.2, R9.2, R10.2, TP1.1, U4.3 (A)
GND: C1.2, C2.2, C3.2, C4.2, C7.2, C8.1, C9.2, C10.2, C11.2, C12.2, C13.2, C14.2, C15.2, C16.2, D1.1 (K), J1.1, J2.2, R2.2, R6.2, U1.7 (GND), U1.8 (GND), U1.9 (GND), U2.2 (GND), U3.1 (GND), U4.2 (K), U5.3 (+), U5.5 (+)
unnamed: C17.1, R15.2, U5.7
unnamed: C18.1, R16.2, U5.1
unnamed: C5.2, D1.2 (A), D2.1 (K)
unnamed: C5.1, D3.2 (A), L1.2, U1.5 (SW), U1.6 (SW)
unnamed: JP1.1 (A), R8.1, TR2.1, TR2.2
unnamed: JP1.2 (B), R7.1
unnamed: JP2.1 (A), R10.1, TR4.1, TR4.2
unnamed: JP2.2 (B), R9.1
unnamed: R13.1, TR1.1
unnamed: R14.1, TR3.1
unnamed: R4.2, U1.1 (EN)
unnamed: C6.2, R5.2, R6.1, U1.3 (FB)
unnamed: R1.2, R2.1, U4.1 (REF)
unnamed: C18.2, R12.1, R14.2, TR4.3, U5.2 (-)
unnamed: C17.2, R11.1, R13.2, TR2.3, U5.6 (-)

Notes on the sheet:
max ca. +5.55V to -5.44V
0.0V to +3.3V
VOUT = 1.25 * (1 + 12k/1k) = 16.25V
SIGNAL SCALE/OFFSET
STEP-UP POWER
CHANGELOG
max ca. -0.2 to +10.8V (UNIPOLAR jumper)
Two pins from Gills PCB ommitted ->
BIPOLAR REGULATED POWER

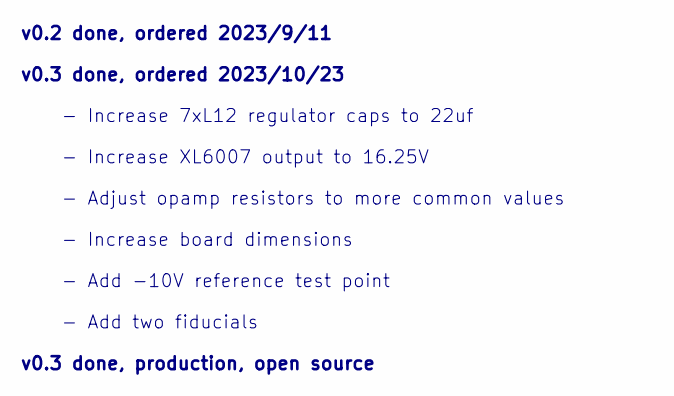
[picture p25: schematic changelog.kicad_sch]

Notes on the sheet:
- Increase 7xL12 regulator caps to 22uf
v0.3 done, ordered 2023/10/23
- Add -10V reference test point
- Increase XL6007 output to 16.25V
- Increase board dimensions
v0.2 done, ordered 2023/9/11
- Add two fiducials
- Adjust opamp resistors to more common values
v0.3 done, production, open source



Board: 2 copper layers, 64.0 x 20.5 mm, 54 parts (6 on the bottom side), 26 nets.

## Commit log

2025-11-19 Update panel kicad_pro
2025-11-19 Add CV Expander project
    [BOM-ksoloti-gills-cv-expander.csv, changelog.kicad_sch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]
2025-11-19 Add cv expander PDF schematic
2025-11-19 Update readmewith CV Expander schematics and BOM info
2025-11-20 Add "CC BY 4.0 Ksoloti" to silkscreens - see README
    [ksoloti-gills-cv-expander.kicad_pcb, ksoloti-gills.kicad_pcb, ksoloti-gills_panel.kicad_pcb]
